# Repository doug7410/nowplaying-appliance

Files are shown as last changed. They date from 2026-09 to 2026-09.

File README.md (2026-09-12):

# Now-Playing appliance

A desk device that listens to the room, figures out what song is playing, and shows it:
a HUB75 LED matrix renders a synced spectrum / lyrics visualization, and a 5" touch
screen shows the cover, title, artist, progress and a mosaic of what played recently.
The whole thing lives in a routed guitar body with three gold knobs and a bat-handle
power toggle.

```
                       room audio
                           │
             ┌─────────────▼──────────────┐
             │  BOARD 1 — the room ear     │  ESP32-S3 running a WLED-MM fork:
             │  I2S mic · HUB75 64×32      │  spectrum / Keybeat / lyrics looks,
             │  panel · 3 knobs            │  uploads mic windows to the cloud
             └──────┬───────────────▲──────┘
      POST /ingest  │               │  GET /lyrics
                    │               │              UART (knobs, re-check, heartbeat)
             ┌──────▼───────────────┴──────┐        │
             │  CLOUD — recognition brain   │        │
             │  songrec → now-playing state │        │
             │  → metadata, lyrics, covers  │        │
             └──────┬───────────────▲──────┘        │
     GET /nowplaying│               │ GET /album/{id}│
             ┌──────▼───────────────┴──────┐        │
             │  BOARD 2 — the touch display │◄───────┘
             │  Raspberry Pi + 5" HDMI/USB  │  native LVGL app (display/)
             └─────────────────────────────┘
```

Both boards authenticate to the cloud with **one shared device token**. The cloud
derives all state server-side; the boards render dumb.

## What is in this repo

| Path | What |
|---|---|
| [`BOM.md`](BOM.md) | The full parts list, with prices and sourcing notes |
| [`docs/assembly.md`](docs/assembly.md) | Order the PCBs, solder them, wire the harness, drill the front panel, first power-on |
| [`docs/board1-firmware.md`](docs/board1-firmware.md) | Build, flash and provision the ESP32-S3 "ear" |
| [`docs/board2-display.md`](docs/board2-display.md) | Set up the Raspberry Pi and run the display app |
| [`docs/cloud.md`](docs/cloud.md) | Running the recognition service and minting the shared token |
| `hardware/carrier-board/` | KiCad source + JLCPCB zip for the interconnect PCB (ESP32-S3 socket, power, HUB75, knobs, mic, Pi) |
| `hardware/knob-board/` | KiCad source + zip for the 3-encoder front-panel PCB. Also the front-panel drilling template |
| `hardware/mic-board/` | KiCad source + zip for the INMP441 breakout adapter |
| `hardware/panelboard/` + [`docs/panelboard.md`](docs/panelboard.md) | **The minimal build:** a standalone HUB75 driver board for a stock ESP32-WROOM-32 dev board, runs upstream WLED-MM unmodified. Just the LED matrix, none of the rest |
| `display/` | The Board 2 display app (LVGL, C++). Runs on the Pi via DRM/KMS, and on a desktop as an SDL simulator |

## Build order

Only want the LED spectrum on a panel? Build the [panelboard](docs/panelboard.md)
instead: one small PCB, a $5 ESP32 dev board, upstream WLED-MM, done. The rest of this
list is the full appliance.

1. Read [`BOM.md`](BOM.md) and order everything. The three PCBs are bare boards from
   JLCPCB, roughly $20 for five of each, hand-soldered.
2. [`docs/assembly.md`](docs/assembly.md): solder the boards, make the four cables, wire
   power, mount the panel and screen.
3. [`docs/cloud.md`](docs/cloud.md): stand up the cloud service and create **one** device
   token. Both boards use it.
4. [`docs/board1-firmware.md`](docs/board1-firmware.md): flash the ESP32-S3 and run the
   provisioning script. The panel should light up with the "Mountain" spectrum.
5. [`docs/board2-display.md`](docs/board2-display.md): image the Pi, run `provision.sh`
   in `display/`. Play a song in the room.

## Status and what is not here yet

This is a working one-off appliance and the design for a small hand-built batch. Every
board in `hardware/` has been fabbed and passes ERC/DRC with zero violations; the pin
maps and current budgets are measured on the bench, not estimated.

Two source trees the build depends on are **not published yet**:

- **The Board 1 firmware** is a fork of [WLED-MM](https://github.com/MoonModules/WLED-MM)
  carrying a `room_mic_uploader` usermod, the Keybeat and lyrics looks, and the HUB75 pin
  map. [`docs/board1-firmware.md`](docs/board1-firmware.md) documents the build exactly
  so it can be reproduced once the fork is pushed.
- **The cloud service** (Laravel + `songrec`). Its HTTP contract is documented in
  [`docs/cloud.md`](docs/cloud.md); the display app in `display/` codes against it.

## License

See [`LICENSE`](LICENSE).

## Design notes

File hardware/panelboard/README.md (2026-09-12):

# panelboard

A minimal board whose only job is driving a HUB75 LED matrix.

No mic, no knobs, no display — 5 V in, a HUB75 connector out, and a plug-in
ESP32 dev board on top. It exists because the Now-Playing appliance's Board 1
does HUB75 rendering buried under a lot of other hardware, and it would be nice
to have the panel half on its own board.

- **MCU:** a stock **ESP32-WROOM-32 38-pin dev board** (the narrow Type-C kind,
  DORHEA/HiLetgo/DevKitC-32 — classic ESP32, *not* an S3), dropped into two 1×19
  female headers. USB, RESET/BOOT and the 3.3 V regulator all come with the
  module, so this board carries none of them.
- **Row spacing is 22.86 mm (0.9").** That is the narrow version, and it is
  measured off the board in hand — a 1.0" wide-version clone is one 0.1" grid
  step wider and **will not seat**. Check yours before ordering.
- **Panel drive:** straight 3.3 V logic, no level shifters. That's what Board 1
  does today and it is hardware-verified on a 64×32 panel.
- **Power:** 5 V in on a screw terminal → AOD403 P-FET reverse-polarity
  protection → a second screw terminal that feeds the panel. Panels pull 2–4 A,
  so the 5 V path is 2.5 mm wide throughout.
- 70 × 72 mm, 2 layers, ground pour on both.

## The pin map is the firmware's, not this repo's

The HUB75 GPIO assignment is **WLED-MM's classic-ESP32 default** — the `#else`
branch at the bottom of `wled00/bus_manager.cpp`, which is the ESP32-Trinity /
mrcodetastic map. Wiring to it means the firmware needs no pinout patch at all.
Don't "improve" it here; change it there and follow.

| HUB75 | GPIO | col | | HUB75 | GPIO | col |
|---|---|---|---|---|---|---|
| R1 | 25 | J1 | | A | 23 | J3 |
| G1 | 26 | J1 | | B | 19 | J3 |
| B1 | 27 | J1 | | C | 5 | J3 |
| R2 | 14 | J1 | | D | 17 | J3 |
| G2 | **12** | J1 | | E | 18 | J3 |
| B2 | 13 | J1 | | LAT | 4 | J3 |
| | | | | OE | 15 | J3 |
| | | | | CLK | 16 | J3 |

**All six RGB pins live in the module's J1 column and all eight control pins in
J3.** That is the single fact the whole layout is built on — see below.

**G2 is on IO12, which is the MTDI strapping pin.** It has to read low at reset
or the chip comes up expecting 1.8 V flash, and the panel's ribbon is the only
other thing on that net. `RPD` (10 k to GND) holds it down rather than trusting
the internal pull-down. It lives under the module: lying flat it is ~2.5 mm tall
against ~8.5 mm of socket clearance.

**E is wired**, to IO18. The 64×32 panel doesn't use it (HUB75 pin 8 is ground
there), but the firmware default already says `e = 18`, so a 64×64 panel is a
config change rather than a respin.

GPIO 6–11 are the SPI flash on a classic ESP32 and are left unconnected, as are
IO0/IO2 (strapping), TX0/RX0, and the input-only pins 34–39.

## Firmware: this is not a drop-in for Board 1's build

A plain ESP-WROOM-32 module is **4 MB flash and no PSRAM**. Board 1's WLED-MM
build (`~/Code/WLED-MM` `platformio_override.ini`, `[env:board1]`) pins
`extreme_partitions` — a 3.2 MB app plus a 9 MB filesystem on 16 MB flash — and
that partition table cannot fit here. Build a stock classic-ESP32 WLED-MM target
for this board. A 64×32 DMA framebuffer fits in internal RAM comfortably; 64×64
at high bit depth will not.

## JP1 — pull the shunt before plugging in USB

A dev board's 5 V pin has no reverse-current protection. Leave it tied to a live
panel supply with a USB cable also plugged in and the supply back-feeds the host
port. `JP1` sits in series with the module's 5 V pin so you can break that path;
it is west of the module body so the shunt has headroom.

## Building it

Everything in `board/` is generated. The `.kicad_sch` and `.kicad_pcb` are
committed artifacts, but the generators are the source of truth — edit those.

```
cd board
make all       # regenerate the schematic and the board from generator/*.py
make check     # ERC + DRC with schematic parity, gating on every severity
make zip       # -> panelboard-jlc.zip, ready to upload to jlcpcb.com
make render    # top.png / bottom.png
```

`gen_sch.py` is deterministic (uuid5-derived), so it re-emits the schematic
byte-for-byte. `gen_pcb.py` is not — pcbnew mints fresh UUIDs on every run, so
`make all` rewrites the whole `.kicad_pcb` even when nothing changed. Regenerate
when the design actually changes, not as a habit.

The board is clean at `--severity-all`: 0 errors, 0 warnings, 0 unconnected,
0 parity issues. There is no expected-warning exception to remember.

## Assembly

**Order it as a bare PCB, not PCBA.** Q1 (AOD403, TO-252) is the only surface
mount part on the board and it hand-solders easily; everything else is through
hole. Paying JLC's assembly setup for one FET is not worth it.

| Ref | Part |
|---|---|
| J_ESP_L, J_ESP_R | 1×19 female header, 2.54 mm |
| J_HUB | 2×08 shrouded IDC header, vertical |
| J_PWR, J_PANEL | Phoenix MSTBVA 2,5/2-G, 5.00 mm |
| JP1 | 1×02 male header + shunt |
| Q1 | AOD403 P-FET, TO-252 |
| RG / RPD | 100 k / 10 k axial |
| CB1 / CB2 | 470 µF 16 V radial D8 / 100 nF disc |

Solder `RPD` before the sockets go in — once the module is plugged in you can't
reach it.

## Layout notes worth knowing before you move anything

- **The HUB75 IDC's pin-1 y is 32.43, not a round number.** That puts every IDC
  row exactly on a *gap* between two J1 socket pads, so each even-column control
  signal crosses the pad wall dead straight — no jog, no via, no chance of
  crossing a neighbour. Move the connector off that grid and eight nets get
  much harder.
- **The control bundle puts every horizontal on B.Cu and every vertical on
  F.Cu.** Two horizontals at different y can't collide and neither can two
  verticals at different x, so the eight nets are collision-proof by
  construction — which matters, because the source order and the destination
  order genuinely disagree (E and B invert, and the four odd-column pins have to
  wrap around the west side of the connector). Costs two vias per net in a
  corridor with room to spare.
- **The corridor between the two socket rows is empty on both layers.** That
  free 22.86 mm channel is the one real thing a socketed module buys you over a
  soldered-down WROOM, and the control fan spends all of it.
- **The board's north edge is at y = 18** so the module's antenna end overhangs
  into free air. The antenna straddles pin 1 — about 3 mm either side — so there
  is no way to socket pin 1 *and* keep the board out from under it. Ending the
  board short is cheaper and better than a copper keepout.
- **Zone clearance is 0.25 mm, not 0.30.** At 0.30 the pour cannot squeeze
  between two 2.54 mm-pitch through-hole pads (2.54 − 2×1.15 = 0.24, under the
  0.25 minimum thickness), the socket rows fence it off, and GND pads end up
  stranded on islands. At 0.25 the gap is 0.34 and it flows. JLC's floor for
  2 layers is 0.2, so this still has margin.
- **Both electrolytics stay south of y = 73.8.** The module's USB port overhangs
  its south end at about 10 mm height and a D8 radial cap is ~11 mm tall — put
  one further north and the cable has nowhere to go.
- The IDC's **shroud courtyard is much larger than its pads** (10 × 29 mm). It
  is the real constraint on the west half of the board, not the pin field.

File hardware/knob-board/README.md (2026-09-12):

# Knob board (KiCad)

The Board-1 front-panel knob PCB: three EC11 rotary encoders (MODE / BRIGHT / GAIN)
plus a switch resistor ladder, out to a single 8-pin JST-XH connector.

This is a **re-creation in KiCad** of the design that was routed in Flux
(`https://www.flux.ai/doug7410/nowplaying-knob-board~ss`). Flux cannot export
`.kicad_pcb`/`.kicad_sch` — only Gerbers, IPC-2581, ODB++, GenCAD and EDIF, none of
which KiCad imports — so the schematic and layout were rebuilt from the Flux Gerber
and IPC-D-356 netlist exports. The KiCad files here are now the source of truth.

## The circuit

Ten nets, six parts. Every footprint is stock KiCad — no custom library.

| Ref | Part | Footprint |
|---|---|---|
| ENC1/2/3 | Alps `EC11E15244G1` | `Rotary_Encoder:RotaryEncoder_Alps_EC11E-Switch_Vertical_H20mm` |
| J1 | JST `B8B-XH-A(LF)(SN)` | `Connector_JST:JST_XH_B8B-XH-A_1x08_P2.50mm_Vertical` |
| R1 | 3.3 kΩ axial | `Resistor_THT:R_Axial_DIN0207_L6.3mm_D2.5mm_P7.62mm_Horizontal` |
| R2 | 10 kΩ axial | same |

**J1 pinout — the harness contract:**

```
1 MODE_A · 2 MODE_B · 3 BRIGHT_A · 4 BRIGHT_B · 5 GAIN_A · 6 GAIN_B · 7 SW_LADDER · 8 GND
```

**The switch ladder.** Three push-switches share one ADC pin. Each switch's common
ties to `SW_LADDER`; the other side goes to GND through a distinct resistance —
ENC1 direct (0 Ω), ENC2 via R1 3.3 kΩ, ENC3 via R2 10 kΩ. The 10 kΩ pull-up to 3V3
and the 100 nF debounce cap live **on the carrier board**, not here; that is why
there is no 3V3 net and the cable is 8 conductors. Levels at GPIO 2 (`ADC1_CH1`):
idle 3.30 V, GAIN 1.65 V, BRIGHT 0.82 V, MODE 0.00 V.

On the KiCad symbol, `A`/`B`/`C` are the rotary section (C is the rotary common →
GND) and `S1`/`S2` are the push-switch. Flux's part model called the same pins
`TERMINAL_A/B/C` and `COM`/`NO`; easy to conflate.

## Geometry

Board **100.0 × 30.0 mm**, rect `(10,10)`–`(110,40)` in KiCad coordinates, centre
`(60,25)`. That frame is deliberately the same one the Flux Gerbers use (Gerber Y is
the negation), so the two can be compared hole-for-hole.

Knob shafts sit at **X = centre −38 / 0 / +38** (38 mm pitch) and **Y = 5 mm above
centre**. The PCB is the front-panel drilling template, so these are the numbers that
have to match the enclosure.

Encoders are on the top layer at 180°; J1, R1 and R2 are on the bottom. The bottom is
a GND pour; the top carries the six quadrature signals.

**Routing.** Pads occupy Y 14.4–25.6 (encoders) and Y 34.59 (J1), leaving a clear
corridor at Y 28–33 across the whole board. Each quadrature signal takes a horizontal
lane there and drops onto its J1 pin; lanes are ordered so no drop ever crosses a lane
still carrying copper at that X. `SW_LADDER` busses all three switch commons and would
have to cross every one of those lanes, so it runs on the **bottom** layer instead —
it just carves a channel through the GND pour, which reconnects around both ends.

## Differences from the Flux board (v2, `a6fcbc93`)

Verified by diffing the drill files:

- **J1, R1, R2 holes are identical** — all 12, exactly.
- **All 15 encoder pins are identical after a deliberate 0.85 mm X shift.** Flux's
  re-route nudged the knob group 0.85 mm right of centre, which broke the left/right
  symmetry (12.85 mm from one edge, 11.15 mm from the other). Here the knobs are
  symmetric: 12.0 mm from each edge.
- **Mounting lugs**: same X, 0.1 mm different in Y, drilled round 2.6 mm vs Flux's
  round 3.0 mm.

This board passes DRC with **0 violations, 0 unconnected pads and 0 schematic-parity
issues**, and JLC's DFM check clean — see below.

## JLC DFM

Ran 2026-08-05 on `knob-board-jlc.zip`: **zero Danger findings in every category** —
no trace/pad spacing, annular ring, edge clearance, soldermask or drill problems.
(The Flux board, by contrast, flagged 21 silkscreen line-width errors, 12
silkscreen-to-pad/hole errors and 11 soldermask-openings-exposing-trace at 0.09 mm.)

Two warnings came back on the first run and are both fixed:

- **Silkscreen line width 0.12 mm (×54).** Stock KiCad footprints ship 0.12 mm silk.
  Everything on F/B.Silkscreen is widened to **0.16 mm** at build time (`SILK_W`), text
  included. Note the exact threshold: **JLC's minimum is 0.153 mm (6 mil), not 0.15** —
  a first attempt at 0.15 mm came back with all 54 warnings intact.
- **Short slot detection 1.3 mm (×6).** The encoder mounting lugs were an oval
  2.8 × 1.5 mm slot; JLC wants a slot at least twice as long as it is wide, and this
  one routed only 1.3 mm. Switched to the stock
  `..._CircularMountingHoles` footprint variant — identical pad positions, but a plain
  round 2.6 mm drill. **The board now has no routed slots at all**, which some fabs
  surcharge for.

If you regenerate the Gerbers, note `make zip` runs `make check` first, so a parity or
DRC regression stops the build rather than silently shipping a stale `gerbers/`.

## Rebuilding

```
make check      # ERC + DRC (with schematic parity); fails on any violation
make gerbers    # gerbers/ + Excellon drill
make zip        # knob-board-jlc.zip — upload this straight to jlcpcb.com
```

`make zip` depends on `check`, so a board that fails DRC can never reach the fab.

**Ordering at JLCPCB:** upload `knob-board-jlc.zip`, then **2 layers, 100 × 30 mm,
1.6 mm, HASL** — every other default is fine. It's a plain 2-layer through-hole board
with no controlled impedance, no blind vias and nothing below 0.35 mm.

Requires `kicad-cli` and the `kicad-library` package (stock symbols and footprints).

Generated output (`gerbers/`, `knob-board-jlc.zip`, `*.rpt`, `*.net`) is gitignored —
the `.kicad_sch` and `.kicad_pcb` are the artifacts that matter.

## Not done

- No silkscreen legend (MODE / BRIGHT / GAIN) next to the knobs — assumed to live on
  the front panel. Say so if the bare board should carry it.
- R1/R2 have no MPN. Irrelevant unless ordering assembly; these are hand-soldered.

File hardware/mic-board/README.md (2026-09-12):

# Now-Playing mic board

Adapter that mounts the proven round **INMP441 I2S MEMS breakout** (Ø14 mm, two
1×3 rows at 7.62 mm) and brings it out to a **6-pin JST-XH** matching the carrier
board's `J_MIC` pinout, 1:1 cable:

| J1 pin | Net | | J1 pin | Net |
|---|---|---|---|---|
| 1 | MIC_SCK | | 4 | GND |
| 2 | MIC_WS | | 5 | P3V3 |
| 3 | MIC_SD | | 6 | GND |

- **L/R is tied to GND on this board** (left channel) — matches WLED-MM
  `digitalmic.type=1` and the Board 1 smoketest wiring.
- Mount the module **label/port side up** (chip side toward this board) on the
  supplied pin headers; the adapter's silk row labels then match the module's.
  The Ø3 mm center hole is acoustic relief so either mounting orientation works.
- Two M3 holes, 14 mm apart, at the top corners.

Built headlessly (kicad-cli 10); `make check` runs ERC + DRC (0 violations,
schematic parity clean), `make zip` builds `mic-board-jlc.zip` for JLCPCB
(2 layers, 20 × 38 mm, 1.6 mm, HASL — bare board, hand-solder the two headers
and the XH).

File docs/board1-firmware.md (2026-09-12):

# Board 1 firmware: the ESP32-S3 ear

Board 1 runs a fork of [WLED-MM](https://github.com/MoonModules/WLED-MM) (MoonModules'
audio-reactive WLED, branch `mdev`) with these additions:

| Piece | What it does |
|---|---|
| `usermods/room_mic_uploader/` | Taps the audio-reactive PCM stream, POSTs mic windows to the cloud's `/ingest`, reads the three EC11 knobs (quadrature in a pin-change ISR), talks to the Pi over UART (knob events, re-check, heartbeat), fetches synced lyrics for the on-panel lyrics look |
| `wled00/FX.cpp` fx 230 "Equalizer LF" | The "Mountain" spectrum: 16 bands, each shown as energy above its own rolling mean |
| `wled00/keybeat_loader.cpp` | Loads beat-synced GIF looks from LittleFS |
| `wled00/bus_manager.cpp` `SECTION9_2_PINOUT` | The HUB75 pin map the carrier board is wired to |
| `pio-scripts/patch_audioreactive.py` | Re-applies a vendored, DSP-patched copy of the audio-reactive usermod after every clean |
| `board1-config/provision-board1.sh` | Post-flash provisioning of everything that lives in WLED's runtime config |

> **Not yet public.** The fork and the vendored assets it pulls from the appliance repo
> (`audio_reactive.h`, the Mountain palette/preset, the Keybeat GIF presets) have not been
> pushed to GitHub yet. Everything below is the exact recipe that builds the shipping
> board, written so it works unchanged once they are. The upstream WLED-MM build alone
> will drive the panel but will not ingest, show lyrics, or talk to the Pi.

## Prerequisites

- PlatformIO (`pip install platformio` or the VS Code extension).
- The ESP32-S3-DevKitC-1 N16R8 on USB (`/dev/ttyACM0` on Linux). **Pull JP1 on the
  carrier first** if the devkit is seated and the carrier is powered.
- A running cloud and the shared device token ([`cloud.md`](cloud.md)).

## 1. Configure the build

Two gitignored files carry the secrets. Create both in the fork's checkout.

`platformio_override.ini`:

```ini
[env:board1]
extends = env:esp32S3_8MB_PSRAM_M_opi

; N16R8 devkit:
board_build.flash_size = 16MB
board_upload.flash_size = 16MB
board_build.partitions = ${esp32.extreme_partitions}   ; 16MB: 3.2MB firmware, 9MB FS
; N8R8 devkit instead: use these three lines. 8MB: 2MB firmware (the build is ~1.9MB), 3.9MB FS
;board_build.flash_size = 8MB
;board_upload.flash_size = 8MB
;board_build.partitions = ${esp32.large_partitions}

upload_port = /dev/ttyACM0
monitor_port = /dev/ttyACM0
upload_speed = 921600
monitor_speed = 115200
monitor_filters = esp32_exception_decoder

build_flags = ${env:esp32S3_8MB_PSRAM_M_opi.build_flags}
  -D WLED_RELEASE_NAME=nowplaying_board1
  -D SECTION9_2_PINOUT              ; HUB75 pins in bus_manager.cpp (matches the carrier)
  -D SR_ENABLE_DEFAULT              ; audioreactive on from first boot
  -D USERMOD_ROOM_MIC_UPLOADER      ; cloud ingest + knobs + UART + lyrics
  -D CLIENT_SSID='"your-wifi-ssid"'
  -D CLIENT_PASS='"your-wifi-password"'
  ; I2S MEMS mic on the carrier: SCK=38 WS=39 SD=40, no MCLK
  -D SR_DMTYPE=1 -D I2S_SDPIN=40 -D I2S_CKPIN=38 -D I2S_WSPIN=39 -D MCLK_PIN=-1
  ; keep WLED's default LED/relay buses off the HUB75 / mic / knob pins
  -D LEDPIN=2 -D RLYPIN=-1

lib_deps = ${env:esp32S3_8MB_PSRAM_M_opi.lib_deps}
```

`usermods/room_mic_uploader/room_mic_uploader_secrets.h` (copy from the `.example`):

```c
#define NP_HOST         "cloud-host-or-ip"   // no scheme; the POST goes over a raw socket
#define NP_PORT         8000
#define NP_INGEST_PATH  "/api/ingest"
#define NP_DEVICE_TOKEN "<the shared appliance token>"   // SAME token as Board 2
```

The vendored `audio_reactive.h` must be reachable at
`../nowplaying/firmware/board1/wled-mm/audio_reactive.h` relative to the fork, or point
`NP_VENDORED_AUDIOREACTIVE` at it. The build fails loudly if it is missing rather than
silently shipping the stock look.

## 2. Build and flash

```sh
pio run -e board1 -t erase  --upload-port /dev/ttyACM0   # clears stale runtime config
pio run -e board1 -t upload --upload-port /dev/ttyACM0
pio device monitor                                        # watch it join WiFi, note the IP
```

## 3. Provision the runtime config

Some of what makes the board work lives in WLED's runtime config on flash, not in the
binary: the HUB75 bus and 2D layout, the **RGB colour order** (this panel swaps red and
green under WLED's GRB default), the local-I2S mic mode with `I2S_FastPath=0`, the boot
preset, the Mountain palette, and the Keybeat GIF assets. A flash erase wipes all of it.
One script restores it:

```sh
./board1-config/provision-board1.sh <board-ip>
```

It POSTs the config, uploads the palette, presets and GIFs, reboots, and verifies
`leds.count == 2048`, audio source `I2S digital`, and boot preset 3 (fx 230, palette
255). It prints `PASS` when the panel is rendering the Mountain look in correct colours
and the mic is ingesting. Idempotent; re-run any time. The config then survives reboots
and OTA updates.

## Knobs

Three bare EC11 encoders: MODE on GPIO 47/48, BRIGHT on 1/12, GAIN on 41/42. Detents
per encoder batch vary (1, 2 or 4 quadrature transitions per click); the divisor is a
calibration constant at the top of `room_mic_uploader.h`. All three push switches share
GPIO 2 through the resistor ladder on the knob board (idle 3.3 V, GAIN 1.65 V, BRIGHT
0.82 V, MODE 0 V). Today only the MODE press does something (jump home); enabling the
other two is a firmware-only change.

The MODE knob cycles looks in the order given by `/npcycle.json` on the board's
filesystem (seeded from `board1-config/npcycle-default.json`). Reorder looks without a
reflash.

## Gotchas that cost real time

- **Panel dark, or red shows green**: runtime config was wiped. Run the provisioning
  script.
- **Mic reads silence (RMS 0)** with a good mic: either `I2S_FastPath` is 1 (the script
  sets 0), or the mic was reseated on a running board. **Reboot after reseating**; I2S
  never recovers from a reconnect on a live board.
- **Panel ghosting**: not seen on this panel at 3.3 V. If a different panel ghosts, put
  an off-the-shelf HUB75 buffer board inline on the ribbon; there is no room for one on
  the carrier.
- **The board and the Pi cannot see each other over WiFi** on many consumer APs (client
  isolation). That is why the knob / re-check link is a UART wire and why the Pi only
  ever talks to the cloud.

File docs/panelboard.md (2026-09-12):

# Panelboard: just the LED matrix

The smallest build in this repo. One 70 × 72 mm board, one stock ESP32 dev board plugged
into it, one HUB75 panel: 5 V in, spectrum out. No mic on the board, no knobs, no
display, no cloud. Upstream WLED-MM drives it unmodified because the board is wired to
WLED-MM's default classic-ESP32 HUB75 pin map (the ESP32-Trinity map).

Design notes, the pin table, and the layout rationale are in
[`hardware/panelboard/README.md`](../hardware/panelboard/README.md). This page is the
build recipe.

## Parts

| Part | Qty | Notes |
|---|---|---|
| Panelboard PCB, `hardware/panelboard/panelboard-jlc.zip` | 1 | JLCPCB: 2 layer, 70 × 72 mm, 1.6 mm, HASL, defaults otherwise. ~$4 for five, bare board |
| **ESP32-WROOM-32 38-pin dev board**, narrow type (DevKitC-32 / HiLetgo / DORHEA, USB-C or micro) | 1 | Classic ESP32, **not** S3. Row spacing must be **0.9" / 22.86 mm**; measure before ordering, a 1.0" clone will not seat |
| 64×32 P4 HUB75 panel, 1/16 scan, with its ribbon and power pigtail | 1 | Same panel as the full appliance |
| 5 V supply, ≥ 3 A, and a way to get it to a screw terminal | 1 | Panel worst case is 2 A (solid white, full brightness); real looks draw ~0.3 A |
| J_ESP_L, J_ESP_R: 1×19 female header, 2.54 mm | 2 | |
| J_HUB: 2×8 shrouded IDC box header, vertical | 1 | |
| J_PWR, J_PANEL: screw terminal, 2 position, 5.00 mm (Phoenix MSTBVA-compatible) | 2 | |
| JP1: 1×2 male header + shunt | 1 | |
| Q1: AOD403 P-channel MOSFET, TO-252 | 1 | The only surface-mount part |
| RG: 100 kΩ axial, RPD: 10 kΩ axial | 1 each | |
| CB1: 470 µF 16 V radial D8, CB2: 100 nF disc | 1 each | |

## Solder

Placement drawings and renders are in `hardware/panelboard/assembly/`
(`placement-top.png`, `placement-bottom.png`, `placement.pdf`, `render-*.png`).

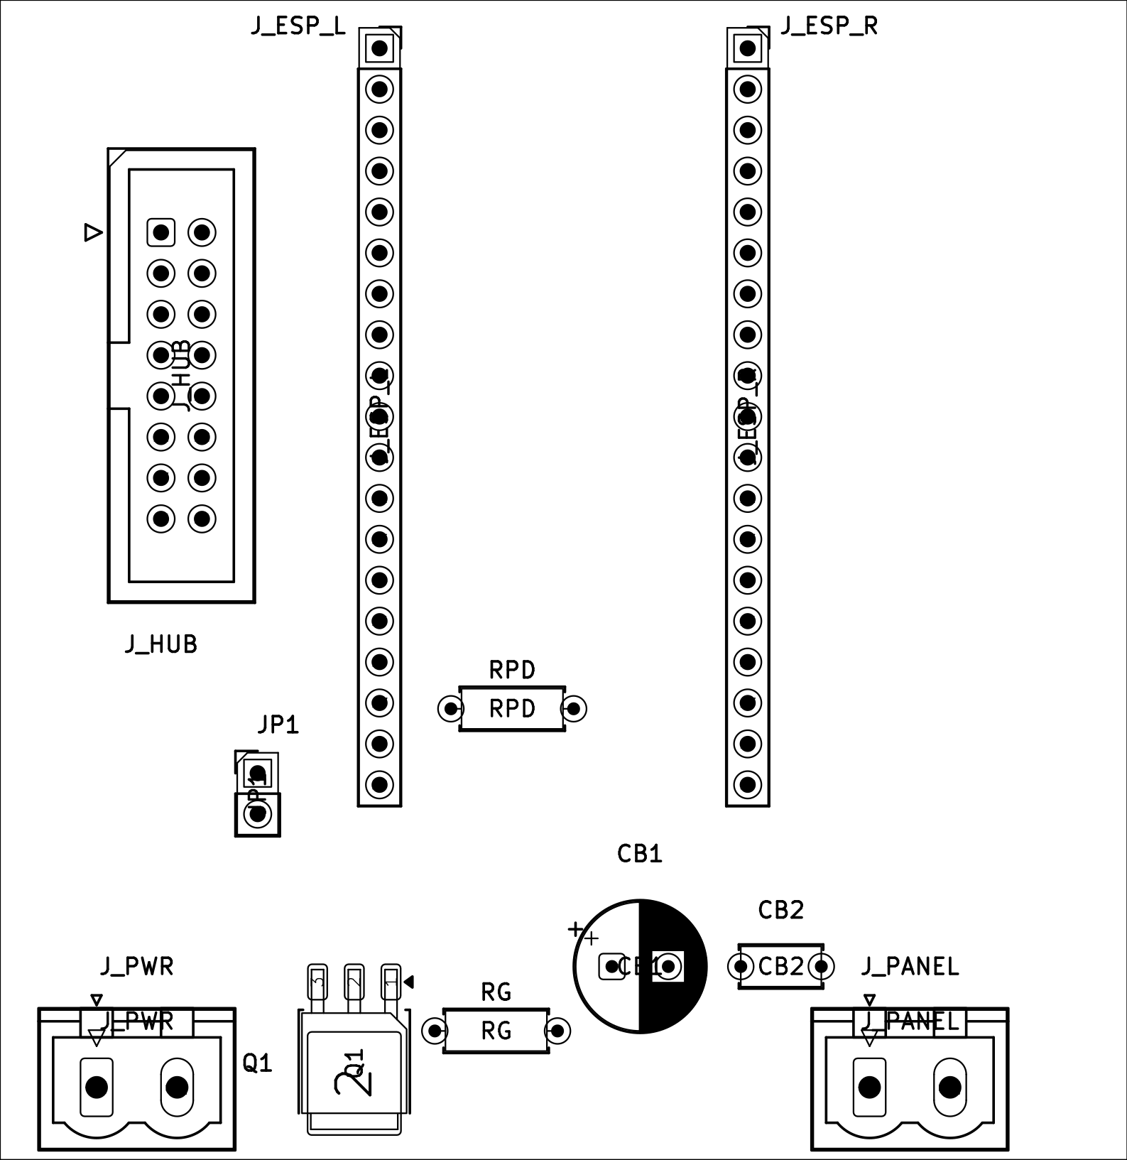
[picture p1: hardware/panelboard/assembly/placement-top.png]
panelboard placement


1. **RPD first.** It sits under the module and is unreachable once the sockets are in.
   It holds IO12 (the G2 line, also the MTDI strapping pin) low at reset; without it
   the chip can come up expecting 1.8 V flash and fail to boot.
2. Q1: tin the tab pad, place, reflow the tab, then the legs. Then RG, CB2, CB1
   (polarity band on the silk).
3. Screw terminals, JP1, the IDC header (key notch as silk-screened).
4. Plug the dev board into both 1×19 sockets, then solder the sockets with the module
   as the alignment jig.

## Wire

```
5 V supply ─► J_PWR ─► Q1 (reverse-polarity) ─► P5V ─┬─► J_PANEL ─► panel power pigtail
                                                     └─► JP1 ─► module 5 V pin
J_HUB ─► panel ribbon ─► panel HUB75 IN
```

The 5 V copper is 2.5 mm wide throughout, sized for the panel's 2–4 A.

**Pull the JP1 shunt before plugging USB into the dev board** while J_PWR is live. The
module's 5 V pin has no reverse-current protection, so a live rail plus a USB cable
back-feeds your computer. Flash over USB with JP1 out, then put the shunt back.

## Firmware

Upstream WLED-MM, branch `mdev`, stock target. Nothing in this repo's Board 1 build
applies: that one needs 16 MB flash and PSRAM, and a plain WROOM-32 has 4 MB and none.

```sh
git clone -b mdev https://github.com/MoonModules/WLED-MM.git && cd WLED-MM
pio run -e esp32_4MB_V4_S_HUB75 -t upload     # JP1 out, USB in
```

That target's HUB75 pinout is the one the board is wired to; do not add a pinout
override. A 64×32 DMA framebuffer fits in internal RAM; 64×64 at high bit depth will
not (the board does wire the E line, so a 64×64 panel is only a config change).

Then join the board to WiFi (WLED-AP captive portal) and, in the web UI:

- **Config → LED Preferences:** LED type **HUB75**, length **2048**, the "pin" field
  is the panel chain length (**1**), colour order **RGB**. The Waveshare P4 panel swaps
  red and green under WLED's default GRB.
- **Config → 2D Configuration:** one panel, **64 × 32**.
- **Config → Sound Settings:** whatever source you have; a UDP sound-sync sender on the
  LAN, or an I2S mic wired to the module's free pins: GPIO 32, 33, 21, 22 are
  unconnected outputs (SCK, WS), and the input-only 34–39 take the data line (SD).
- Pick an audio-reactive 2D effect (GEQ, Waverly, 2D Swirl...) and save it as the boot
  preset.

Those settings live in the board's flash config, not the binary. Export them from
Config → Security & Updates → Backup once you like them.

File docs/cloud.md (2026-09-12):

# The cloud: recognition service

The boards do no recognition themselves. Board 1 uploads short mic windows; a Laravel
service runs them through [`songrec`](https://github.com/marin-m/SongRec) (a headless
Shazam client), derives per-appliance now-playing state, enriches it in a queue worker
(duration and tracklist from iTunes, synced lyrics from NetEase / LRCLIB, covers via
Cloudinary), and serves it back over five HTTP endpoints. One instance serves any number
of appliances; each appliance is a tenant identified by its bearer token.

> **Not yet public.** The service source is not published. This page documents the
> contract the boards are built against and what running an instance involves, so the
> rest of the build is reproducible the day it is.

## Running an instance

- PHP 8.3 + Composer, SQLite (local) or Postgres.
- `songrec` 0.7.3 on the PATH (`songrec audio-file-to-recognized-song <wav>` is the
  only call made).
- A Cloudinary account with **fetched URLs enabled** for cover-art resizing.
- Two foreground processes:

```sh
php artisan serve --host=0.0.0.0 --port=8000        # bind the LAN so the boards reach it
php artisan queue:work --queue=database --tries=1   # fills duration / lyrics / album
```

Config knobs in `.env`: `NP_FRESHNESS_TIMEOUT=90` (seconds without an ingest before the
state decays), `NP_IDLE_AFTER=3` (consecutive misses before `idle`), `NP_RECENT_MAX=90`.
The defaults fit the boards' cadences (Board 1 uploads every ~33 s, Board 2 polls every
3–5 s). Leave them.

## Mint the appliance token

```sh
php artisan device:create      # prints the token once
```

**One appliance = one device = one token.** Put the same token in Board 1's
`room_mic_uploader_secrets.h` and Board 2's `pi/np.env`. Both `/nowplaying` and the
recent mosaic are scoped to the authenticated device, so a second token is a second,
empty appliance that shows "Listening" forever.

## The contract

All endpoints except `/health` take `Authorization: Bearer <token>`. CORS is open
(`Access-Control-Allow-Origin: *`) so a browser on the LAN can also read it.

| Method + path | Caller | Purpose |
|---|---|---|
| `GET /api/health` | anyone | liveness, no auth |
| `POST /api/ingest` | Board 1 | multipart field `file`: a **16 kHz mono 16-bit PCM WAV**, 8–18 s, RMS-gated. Recognised inline. Returns `{matched, track_id, title, artist}` |
| `GET /api/nowplaying` | Board 2 | current state + track + cover + position + recent tiles |
| `GET /api/album/{id}` | Board 2 | tracklist for a recent tile, the heard track flagged |
| `GET /api/lyrics?track_id=…` | Board 1 | synced `yrc` / `lrc`; `pending: true` until the worker has run |

`GET /api/nowplaying`:

```json
{ "state": "playing",
  "track_id": "…", "title": "…", "artist": "…", "album": "…",
  "cover_url": "https://res.cloudinary.com/…",
  "duration_s": 301, "position_s": 42.0,
  "lyrics_available": true,
  "recent": [ { "id": "…", "cover_url": "…" } ] }
```

- `state` is `setup`, `playing` or `idle`, derived server-side. Track fields are null
  unless `playing`.
- `position_s` is computed at request time. Interpolate the progress bar from the
  moment the response arrived and re-snap on every poll; there is no anchor timestamp.
- `recent[]` tiles carry only `id` and `cover_url`; `id` feeds `/album/{id}`.
- The WAV upload is MIME-sniffed. A malformed header is a 422 even if the PCM decodes.
  This is the number-one real-hardware failure mode.

## A note on recognition

`songrec` talks to Shazam's unofficial endpoint. It is free and it works, and it is also
a terms-of-service and reliability risk for anything you sell: if the endpoint changes,
every fielded unit goes quiet until the cloud is patched. The design keeps all vendor
calls server-side for exactly that reason, so swapping to a licensed API (AudD, ACRCloud)
is a cloud-only change that never touches a board.

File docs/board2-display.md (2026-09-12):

# Board 2: the Raspberry Pi display

Board 2 is a Raspberry Pi driving the 5" 800×480 HDMI touch panel with the native
LVGL app in [`display/`](../display/README.md). No desktop, no compositor, no browser:
the app draws straight to the screen through DRM/KMS on tty1 and reads touch from evdev.
It polls the cloud's `GET /nowplaying` every few seconds and `GET /album/{id}` when a
cover is tapped, and renders four screens: Now Playing, Listening (idle), Recently
(cover mosaic), Album.

Verified on a Pi 3B. Any Pi with a 40-pin header and HDMI out works; the app's working
set is 30–60 MB.

## 1. Image the Pi

Raspberry Pi OS **Lite** (Debian 12 or 13), 64-bit. In the imager set a hostname, a
user, WiFi, and enable SSH. Boot it headless and `ssh` in.

## 2. Free the UART for the Board 1 link

The carrier's J_PI cable puts Board 1's serial on header pins 8/10. Take Bluetooth off
the good UART and stop the kernel using it as a console:

```sh
sudo sed -i 's/ console=serial0,115200//' /boot/firmware/cmdline.txt
printf 'enable_uart=1\ndtoverlay=disable-bt\n' | sudo tee -a /boot/firmware/config.txt
sudo systemctl disable serial-getty@ttyS0 serial-getty@ttyAMA0
sudo reboot
```

After the reboot `/dev/serial0` is the PL011 (`ttyAMA0`), 115200 8N1.

## 3. Build and install the display app

On the Pi:

```sh
git clone <this repo> && cd nowplaying-appliance/display
cp pi/np.env.example pi/np.env
$EDITOR pi/np.env          # NP_BASE_URL = http://<cloud-host>:8000/api
                           # NP_TOKEN    = the SHARED appliance token (same as Board 1)
./provision.sh             # apt deps → cmake build → np-display.service on tty1
```

`provision.sh` is idempotent: re-run it after pulling changes. It installs a systemd
unit that owns tty1 (`Conflicts=getty@tty1`, `PAMName=login` so the process gets a
logind seat and can take DRM master) and restarts on failure. Logs:

```sh
journalctl -u np-display -f
```

If DRM will not initialise on your Pi/OS combination, `DISPLAY_BACKEND=fbdev
./provision.sh` writes `/dev/fb0` directly instead. It tears slightly but never fights
for DRM master.

The touch panel enumerates as `/dev/input/event0` (QDtech MPI5001). If it lands
elsewhere, set `NP_TOUCH_DEV` in `pi/np.env`.

## 4. The one trap: the token

`/nowplaying` and the recent mosaic are scoped **per device**. If the Pi uses a token
other than the one Board 1 ingests under, it reads an empty tenant and shows
"Listening" forever, with no error anywhere. One appliance, one token, on both boards.

## 5. Make it survive the power toggle

The master toggle is a hard cut. Either enable the overlay read-only root
(`sudo raspi-config` → Performance → Overlay File System) once everything is set up, or
on a Pi 4 boot from a USB SSD. Remember to disable the overlay before the next
`provision.sh`.

## 6. Seeing it without hardware

`display/sim/run.sh` builds the same `src/ui.cpp` into an 800×480 SDL window on a
desktop, fed by the live cloud (needs SDL2 + libcurl dev packages, and
`src/secrets.h` copied from its `.example` with the token). Mouse = touch, drag to page
the mosaic. This is where the UI is developed; the Pi build only swaps the platform
layer.

## Known gaps

- The knob-toast, re-check and "ear down" overlays are present in the UI but the
  UART bridge that drives them in the LVGL app is not wired up yet (the frame codec
  is `display/src/uart_link.h`; the ESP32 side already sends). They stay dormant until
  that lands.
- The accent colour is fixed rather than sampled from the cover.

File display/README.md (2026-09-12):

# nowplaying-display

Native **LVGL** display app for the Now-Playing appliance's Board 2 (the touch screen).
Replaces the Chromium kiosk (`~/Code/nowplaying-pi`) so it fits a 512 MB Pi
(Zero 2 W / 3A+) — LVGL's working set is ~30–60 MB vs Chromium's ~450 MB.

Renders the same four-screen 800×480 design (Now Playing / Listening / Recently / Album)
the kiosk built, fed by the frozen cloud contract (`GET /nowplaying`, `GET /album/{id}`).

## Layout

- `src/ui.cpp` — the LVGL UI (the screens). The only file with the new design in it.
- `src/ui.h` / `ui_platform.h` — UI public surface + the host shims it needs.
- `src/now_playing.h` — the cloud contract structs (`NowPlaying`, `Album`, …).
- `src/uart_link.h` — codec for the deferred ESP32↔Pi knob/recheck bridge.
- `sim/` — SDL desktop simulator: runs `src/ui.cpp` in an 800×480 window against the
  **live** cloud (libcurl + stb_image in `backend.cpp`). This is how you see it without
  hardware.

## Run the sim

```sh
cp src/secrets.h.example src/secrets.h   # fill in BASE_URL + the SHARED appliance token
cd sim && ./run.sh                        # first run fetches LVGL + stb_image + json
```

Needs SDL2 + libcurl dev packages. Mouse = touch; drag to page the mosaic.

## On the Pi

`pi/` is the platform layer the sim's `sim/` is to SDL: LVGL on the Linux **DRM/KMS**
(default) or **fbdev** display driver + **evdev** touch — no compositor, no browser. It
reuses `src/ui.cpp`, `src/now_playing.h`, and `sim/backend.cpp` unchanged; only the entry
point (`pi/main.cpp`) and `pi/lv_conf.h` differ from the sim.

Deploy mirrors the kiosk (`provision.sh` + a systemd unit), run **on the Pi**:

```sh
cp pi/np.env.example pi/np.env     # set NP_TOKEN (the SHARED appliance token) + NP_BASE_URL
./provision.sh                     # apt deps -> build -> install + start np-display.service
#   DISPLAY_BACKEND=fbdev ./provision.sh   # if DRM won't win master on the VT
```

Notes:
- Token/host come from `pi/np.env` via the unit's `EnvironmentFile` (out of git + the binary);
  `backend.cpp` reads `NP_TOKEN`/`NP_BASE_URL` env, falling back to `src/secrets.h`.
- DRM master is exclusive — the unit takes tty1 (`Conflicts=getty@tty1`, `PAMName=login`)
  and `provision.sh` disables the old `np-kiosk`. fbdev sidesteps the master fight.
- Touch panel = `/dev/input/event0` (QDtech MPI5001); override with `NP_TOUCH_DEV` if it moves.
- Build only the app target: `cmake --build pi/build --target np-display` (skips lvgl demos).

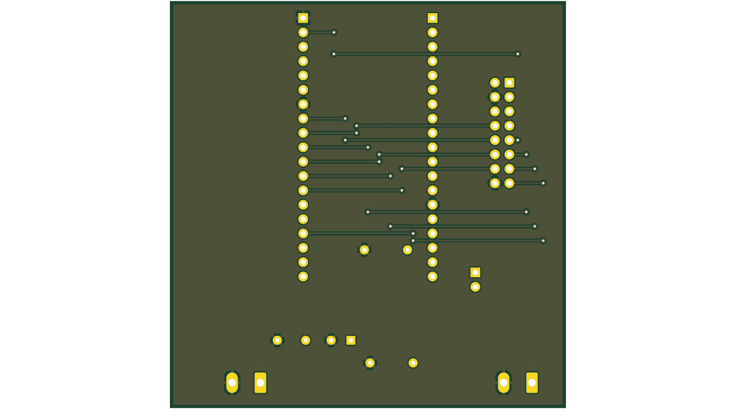
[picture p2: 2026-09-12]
hardware/panelboard/bottom.png

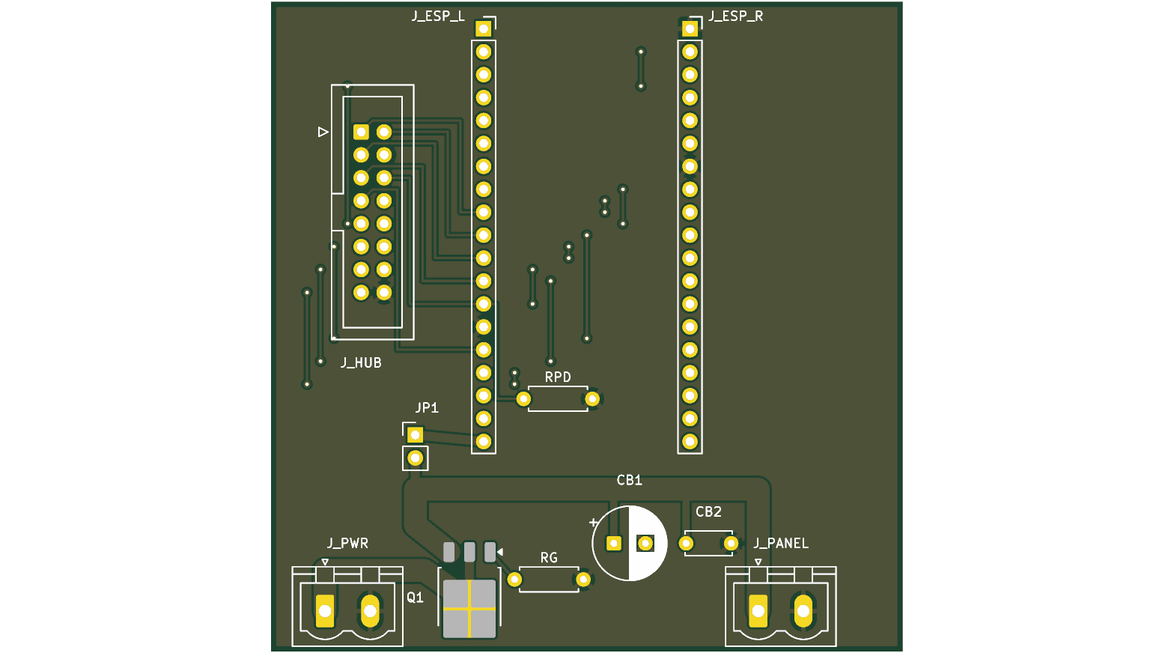
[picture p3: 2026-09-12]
hardware/panelboard/top.png

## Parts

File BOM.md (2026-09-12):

# Bill of materials

One appliance = Board 1 (ESP32-S3 "ear") + Board 2 (Raspberry Pi display) + the
interconnect PCBs + one enclosure. Prices are USD, small-quantity retail, rounded. Where
a part is a specific SKU that matters, it says so and why.

The custom PCBs are ordered as **bare boards** and hand-soldered. Every part on them is
through-hole except one DPAK MOSFET, which hand-solders fine.

## Board 1 — the ear

| # | Part | Qty | ~$ | Notes |
|---|---|---|---|---|
| 1 | **ESP32-S3-DevKitC-1**, genuine Espressif: **N16R8** (16 MB flash, 8 MB octal PSRAM) or **N8R8** (8 MB flash) | 1 | 15 | Plugs into the carrier's two 1×22 sockets. **Must be the genuine Espressif board with 22.86 mm (0.9") row spacing**: [Espressif's dimension drawing](https://dl.espressif.com/dl/schematics/esp_idf/DXF_ESP32-S3-DevKitC-1_V1.1_20220429.pdf) shows a 25.40 mm board with each pin row inset 1.27 mm, and the [user guide](https://docs.espressif.com/projects/esp-dev-kits/en/latest/esp32s3/esp32-s3-devkitc-1/user_guide_v1.1.html) says all -1 / -1U variants share that PCB. Every Amazon "N16R8 DevKitC-1" listing is a clone with 1.0" rows and will not seat. Buy from Mouser: N8R8 is stocked (`356-EP32S3DVKTC1N8R8`); N16R8 (`356-ESP32S3DKC1N16R8`) is factory-order. N8R8 needs the 8 MB partition table, see the firmware page; the firmware and assets fit either. |
| 2 | **64×32 P4 HUB75 LED matrix**, 1/16 scan, e.g. Waveshare RGB-Matrix-P4-64x32 | 1 | 30 | Buy a branded, restockable SKU new. Comes with the 16-pin ribbon and the power pigtail. Driven at 3.3 V logic with no level shifter, bench-verified. |
| 3 | **INMP441 I2S MEMS mic breakout**, the round Ø14 mm module with two 1×3 rows 7.62 mm apart | 1 | 3 | The mic board is cut for this exact module. INMP441 is EOL at TDK but modules are plentiful. Do not substitute SPH0645: WLED-MM's SPH0645 timing fix is classic-ESP32 only and is a no-op on the S3. |
| 4 | Carrier board PCB, `hardware/carrier-board/carrier-board-jlc.zip` | 1 | 11 / 5 pcs | JLCPCB: 2 layer, 140 × 100 mm, 1.6 mm, 1 oz, HASL. Everything else default. |
| 5 | Knob board PCB, `hardware/knob-board/knob-board-jlc.zip` | 1 | 2 / 5 pcs | JLCPCB: 2 layer, 100 × 30 mm, 1.6 mm, HASL. |
| 6 | Mic board PCB, `hardware/mic-board/mic-board-jlc.zip` | 1 | 4 / 5 pcs | JLCPCB: 2 layer, 20 × 38 mm, 1.6 mm, HASL. |
| 7 | Carrier board parts (table below) | 1 set | 8 | |
| 8 | Knob board parts (table below) | 1 set | 6 | |
| 9 | Mic board parts (table below) | 1 set | 1 | |
| 10 | Knob caps, 6 mm D-shaft, set-screw, gold knurled dome | 3 | 6 | Guitar-knob aesthetic. |
| 11 | **Master power toggle**: SPST bat-handle, rated ≥10 A DC, gold, with a Gibson-style "poker chip" ring | 1 | 6 | Switches the 5 V rail, never mains. RHYTHM up = ON. |
| 12 | **Panel-mount DC jack**, DC-099 style, 5.5 × 2.1 mm, threaded | 1 | 2 | Bolts through the enclosure wall so plug force lands on the wood, not a PCB. |
| 13 | **5 V power brick**, 5.5 × 2.1 mm plug, **≥ 6 A** (10 A gives headroom) | 1 | 25 | Measured budget: panel 2.0 A worst case (solid white, full brightness; 0.3 A in real use), Pi up to 3 A, ESP32 0.5 A. The brick stays outside the enclosure. |

### Carrier board parts

Matches `hardware/carrier-board/assembly/bom-jlc.csv` (LCSC part numbers are in that
file). All through-hole except Q1.

| Ref | Part | Qty | Footprint |
|---|---|---|---|
| Q1 | AOD403 P-channel MOSFET (reverse-polarity protection) | 1 | TO-252 / DPAK |
| R1–R7 | 10 kΩ ¼ W axial | 7 | axial, 7.62 mm pitch |
| RG | 100 kΩ ¼ W axial | 1 | axial |
| C1–C6 | 10 nF 50 V X7R leaded ceramic | 6 | disc, 5 mm pitch |
| C3V3, C7, CB2 | 100 nF X7R leaded ceramic | 3 | disc, 5 mm pitch |
| CB1 | 470 µF 10 V electrolytic | 1 | radial D8, 3.5 mm pitch |
| J_PWR, J_SW, J_PANEL | Screw terminal, 2 position, 5.00 mm pitch | 3 | Phoenix MSTBVA-compatible (KF2EDGVC-5.0-2P clones are fine) |
| J_KNOBS | JST B8B-XH-A | 1 | XH 2.5 mm, 8 pin |
| J_MIC | JST B6B-XH-A | 1 | XH, 6 pin |
| J_PI | JST B5B-XH-A | 1 | XH, 5 pin |
| JP1, JP2, JP3 | 1×2 pin header 2.54 mm **+ 3 shunts** | 3 | |
| J_ESP_L, J_ESP_R | 1×22 female pin socket 2.54 mm | 2 | The ESP32-S3 devkit plugs in here |
| J_HUB | 2×8 IDC box header 2.54 mm, shrouded, with key notch | 1 | The panel ribbon plugs in here |

### Knob board parts

| Ref | Part | Qty |
|---|---|---|
| ENC1–3 | Alps **EC11E15244G1** rotary encoder with push switch, 20 mm shaft, threaded bushing | 3 |
| J1 | JST B8B-XH-A | 1 |
| R1 | 3.3 kΩ ¼ W axial | 1 |
| R2 | 10 kΩ ¼ W axial | 1 |

### Mic board parts

| Ref | Part | Qty |
|---|---|---|
| J1 | JST B6B-XH-A | 1 |
| — | 1×3 pin header, 2.54 mm (mounts the INMP441 module) | 2 |

### Cables

| Cable | From → to | Notes |
|---|---|---|
| Knobs | carrier J_KNOBS → knob board J1 | 8-conductor JST-XH, **straight through 1:1** |
| Mic | carrier J_MIC → mic board J1 | 6-conductor JST-XH, straight through |
| Pi | carrier J_PI → Pi 40-pin header pins 2, 4, 6, 8, 10 | 5-conductor: XH housing on one end, 2.54 mm female Dupont on the other. Straight through; the UART crossover is on the carrier. |
| Panel data | carrier J_HUB → panel HUB75 IN | The 16-pin ribbon that ships with the panel |
| Panel power | carrier J_PANEL → panel power connector | The pigtail that ships with the panel, into the screw terminal. Do not run panel current through anything thinner. |
| DC in | jack lugs → carrier J_PWR; toggle → carrier J_SW | 18 AWG or heavier, carries the full ~6 A |

JST-XH housings + crimp contacts (or pre-crimped XH leads) for 8, 6 and 5 positions.

## Board 2 — the display

| # | Part | Qty | ~$ | Notes |
|---|---|---|---|---|
| 1 | **Raspberry Pi** with a 40-pin header and HDMI out | 1 | 35–55 | The display app is native LVGL (~30–60 MB), so RAM is not a constraint. **Verified on a Pi 3B**; a Pi 4 (2 GB) is the pick for a new build (in production, supports USB boot). A Zero 2 W is the app's design target but not yet hardware-verified, and needs a mini-HDMI adapter and a micro-USB OTG cable for the touch panel. |
| 2 | microSD, 16 GB+, endurance grade (or a USB SSD on a Pi 4) | 1 | 8 | The master toggle is a hard power cut. Use read-only root (overlayfs) or USB boot so cuts are safe. |
| 3 | **5" 800×480 IPS HDMI display with USB capacitive touch**, USB-powered (Hosyond; the touch controller enumerates as QDtech MPI5001) | 1 | 40 | HDMI video + USB touch = zero GPIO use. **Avoid** the DSI variant and resistive eBay units. Verify the listing says capacitive. |
| 4 | Short HDMI cable (Pi 3B/4: full/micro HDMI to HDMI as appropriate) | 1 | 4 | |
| 5 | Short USB-A to micro-USB cable | 1 | 2 | Screen power + touch, from a Pi USB port |

The Pi has **no separate power supply**: it is fed 5 V on header pins 2 and 4 from the
carrier board through the master toggle. Powering over the header bypasses the Pi's
input fuse and polyfuse, which is fine here because the carrier's MOSFET and the brick's
own protection are upstream.

## Enclosure

| Part | Notes |
|---|---|
| Double-cut guitar body blank (or a used body) | Displays inset into the top, control cavity routed from the rear, jack-plate power inlet on the rim |
| Front acrylic: **TAP Plastics Chemcast "Black LED" 1/8"** | Black when off, transmits when lit. **Not** "Black Opaque" (0 % transmission). Gray smoke acrylic is the cheap substitute. |
| Diffuser: **TAP frosted P95 "Lighting White" 69 % transmission, 1/8"** | **Not** Matte White 9 % (too dim), **not** clear (hot spots). |
| M2.5 nylon standoff kit | Stack to a ~5 mm air gap between panel and diffuser. Tune softness with the gap. |
| Passive heatsink for the Pi | **No fan**: the mic would hear it. Vent the cavity. |
| Fasteners, hookup wire, heat-shrink | |

## Panelboard: the matrix-only build

Not part of the appliance; an alternative to it. One PCB, one stock ESP32-WROOM-32 dev
board, one panel, one 5 V supply. Full parts table and recipe in
[`docs/panelboard.md`](docs/panelboard.md).

| Bucket | ~$ |
|---|---|
| Panelboard PCB (5 pcs) + parts | 12 |
| ESP32-WROOM-32 38-pin dev board (narrow, 0.9" rows) | 5 |
| 64×32 P4 HUB75 panel | 30 |
| 5 V ≥3 A supply | 10 |
| **Total** | **~$57** |

## Roll-up

| Bucket | ~$ |
|---|---|
| Board 1 electronics (incl. PCBs and parts) | 115 |
| Board 2 electronics | 95 |
| Cables, switch, jack, brick | 35 |
| Enclosure materials | 40–130 |
| **Total materials** | **~$285–375** |

Cloud hosting is an operating cost shared across all appliances, not a per-unit part.

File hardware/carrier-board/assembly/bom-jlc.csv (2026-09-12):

Comment | Designator | Footprint | LCSC Part #
AOD403 P-FET | Q1 | TO-252-3_TabPin2 | C28969
10k axial 1/4W | R1,R2,R3,R4,R5,R6,R7 | R_Axial_DIN0207_P7.62mm | C61299
100k axial 1/4W | RG | R_Axial_DIN0207_P7.62mm | C120103
10nF 50V X7R leaded MLCC | C1,C2,C3,C4,C5,C6 | C_Disc_D5.0mm_P5.00mm | C1620232
100nF 100V X7R leaded MLCC | C3V3,C7,CB2 | C_Disc_D5.0mm_P5.00mm | C1622885
470uF 10V radial D8 P3.5 | CB1 | CP_Radial_D8.0mm_P3.50mm | C1579341
Screw terminal header 5.00mm 2P (MSTBVA-compatible) | J_PWR,J_SW,J_PANEL | PhoenixContact_MSTBVA_2,5_2-G | C441375
JST B8B-XH-A | J_KNOBS | JST_XH_B8B-XH-A_Vertical | C157972
JST B6B-XH-A | J_MIC | JST_XH_B6B-XH-A_Vertical | C144397
JST B5B-XH-A | J_PI | JST_XH_B5B-XH-A_Vertical | C157991
Pin header 1x2 2.54mm | JP1,JP2,JP3 | PinHeader_1x02_P2.54mm | C32713268
Pin socket 1x22 2.54mm | J_ESP_L,J_ESP_R | PinSocket_1x22_P2.54mm | C41376161
IDC box header 2x8 2.54mm | J_HUB | IDC-Header_2x08_Latch | C53207556

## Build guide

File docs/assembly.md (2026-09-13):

# Assembly

Order: fab the PCBs → solder them → make the cables → wire power → bench test with
nothing seated → seat the boards → mount in the enclosure.

## 1. Order the PCBs

Upload each zip to jlcpcb.com. Every board is a plain 2-layer through-hole board: no
controlled impedance, no blind vias, nothing under 0.35 mm. Defaults are fine except
the size, which JLC reads from the Gerbers anyway.

| Board | File | Size | Copper |
|---|---|---|---|
| Carrier | `hardware/carrier-board/carrier-board-jlc.zip` | 140 × 100 mm | **1 oz** (the 5 V traces are 4 mm wide, sized for 1 oz at 6 A) |
| Knob | `hardware/knob-board/knob-board-jlc.zip` | 100 × 30 mm | 1 oz |
| Mic | `hardware/mic-board/mic-board-jlc.zip` | 20 × 38 mm | 1 oz |

Order bare boards, no assembly. All three passed JLC's DFM check with zero Danger
findings. To regenerate a zip from source you need `kicad-cli` (KiCad 9/10) plus the
stock symbol and footprint libraries; `make zip` in each board directory runs ERC + DRC
first and refuses to build from a board with violations.

## Where the parts go

Every board directory has an `assembly/` folder with placement drawings and renders,
regenerated from the KiCad files by `hardware/render-assembly.sh`:

| File | What |
|---|---|
| `placement-top.png`, `placement-bottom.png` | Outline + footprint outlines + reference designators, as you look at that side (bottom is mirrored) |
| `placement.pdf` | The same, one page per layer, printable |
| `render-top.png`, `render-bottom.png` | 3D render of the bare board with silkscreen |

Carrier board, top:

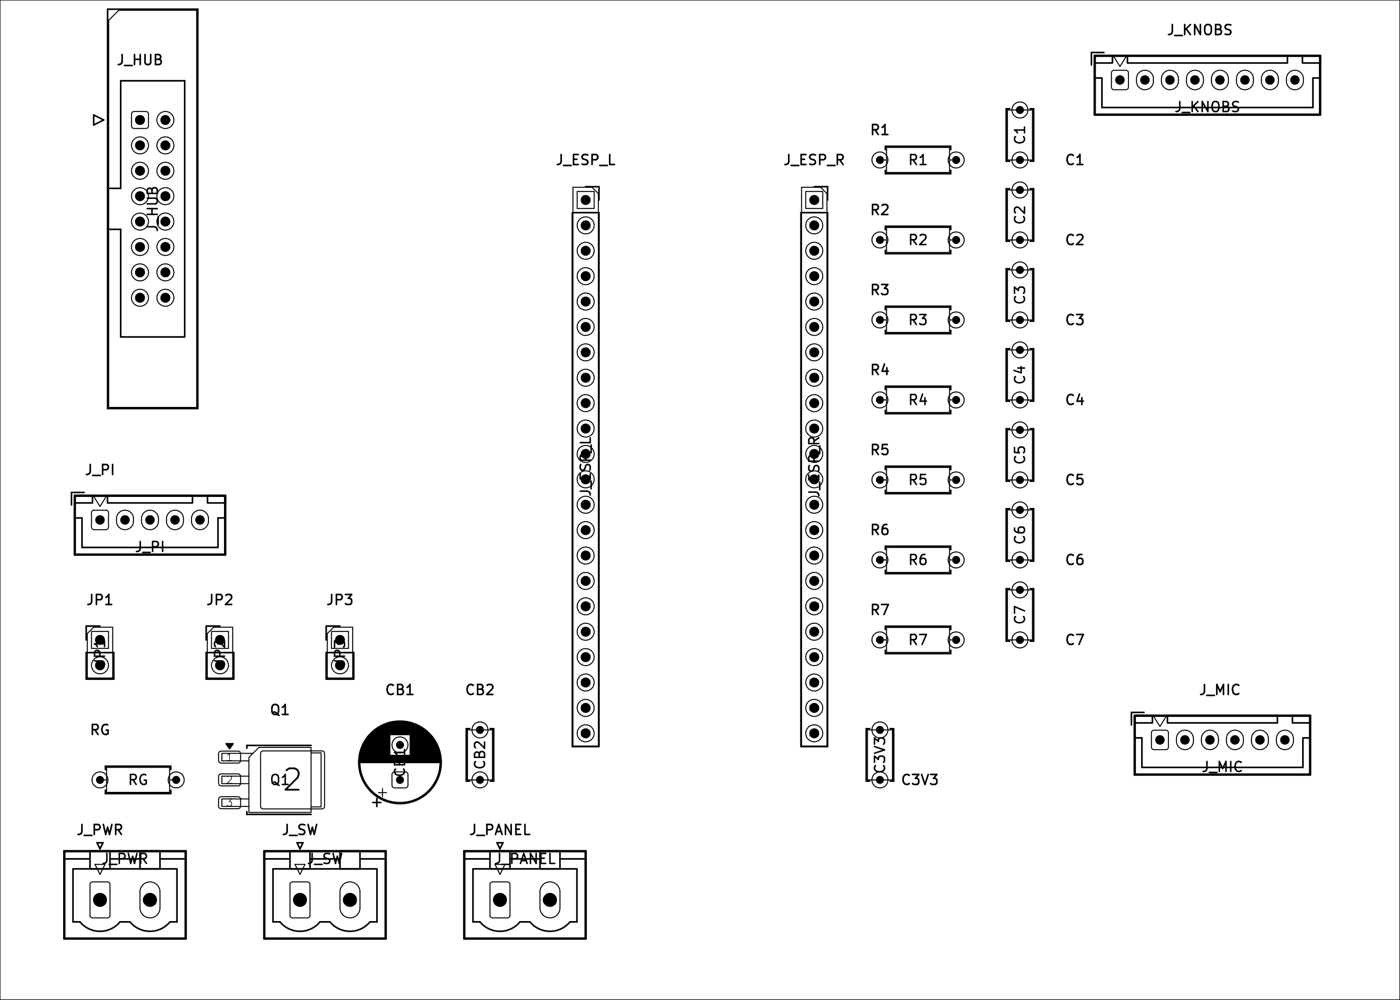
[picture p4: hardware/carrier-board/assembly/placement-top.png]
carrier board placement


## 2. Solder the carrier board

Parts (LCSC numbers in `hardware/carrier-board/assembly/bom-jlc.csv`):

| Ref | Part | Qty |
|---|---|---|
| Q1 | AOD403 P-channel MOSFET, TO-252 / DPAK | 1 |
| R1–R7 | 10 kΩ ¼ W axial | 7 |
| RG | 100 kΩ ¼ W axial | 1 |
| C1–C6 | 10 nF 50 V X7R leaded ceramic, 5 mm pitch | 6 |
| C3V3, C7, CB2 | 100 nF X7R leaded ceramic, 5 mm pitch | 3 |
| CB1 | 470 µF 10 V electrolytic, radial D8, 3.5 mm pitch | 1 |
| J_PWR, J_SW, J_PANEL | Screw terminal, 2 position, 5.00 mm pitch | 3 |
| J_KNOBS | JST B8B-XH-A | 1 |
| J_MIC | JST B6B-XH-A | 1 |
| J_PI | JST B5B-XH-A | 1 |
| JP1, JP2, JP3 | 1×2 pin header 2.54 mm + shunt | 3 |
| J_ESP_L, J_ESP_R | 1×22 female pin socket 2.54 mm | 2 |
| J_HUB | 2×8 IDC box header 2.54 mm, shrouded, keyed | 1 |

Order of operations: shortest parts first. Resistors and ceramics, then Q1, then CB1,
then the headers and sockets, then the screw terminals and JST connectors, then the IDC
header.

- **Q1 (AOD403, DPAK)** is the only surface-mount part. Tin the tab pad, place, reflow
  the tab with a broad tip, then the two legs. Orientation: the silk shows the outline
  and pin 1.
- **CB1 (470 µF)** is polarized. The silk has a hatched band on the negative side.
- **J_ESP_L / J_ESP_R sockets**: plug the ESP32-S3 devkit into both sockets *before*
  soldering them so they end up parallel, then solder with the devkit as the jig. Row
  spacing is 22.86 mm; if your devkit does not drop in freely it is the wrong (1.0")
  board, see the BOM.
- **J_HUB (IDC 2×8)**: key notch faces the board edge, matching the ribbon's key. Pin 1
  is marked on the silk.
- **JST connectors**: shroud opening (pin 1 mark) as silk-screened.
- Fit **shunts on JP1, JP2, JP3** for normal operation. See §5 for when to pull them.

Nets and connector pinouts are in `hardware/carrier-board/generator/gen_carrier_sch.py`
(the schematic is generated from that file, so the file is the readable version).

## 3. Solder the knob board

| Ref | Part | Qty |
|---|---|---|
| ENC1–3 | Alps EC11E15244G1 rotary encoder with push switch, 20 mm shaft, threaded bushing | 3 |
| J1 | JST B8B-XH-A | 1 |
| R1 | 3.3 kΩ ¼ W axial | 1 |
| R2 | 10 kΩ ¼ W axial | 1 |

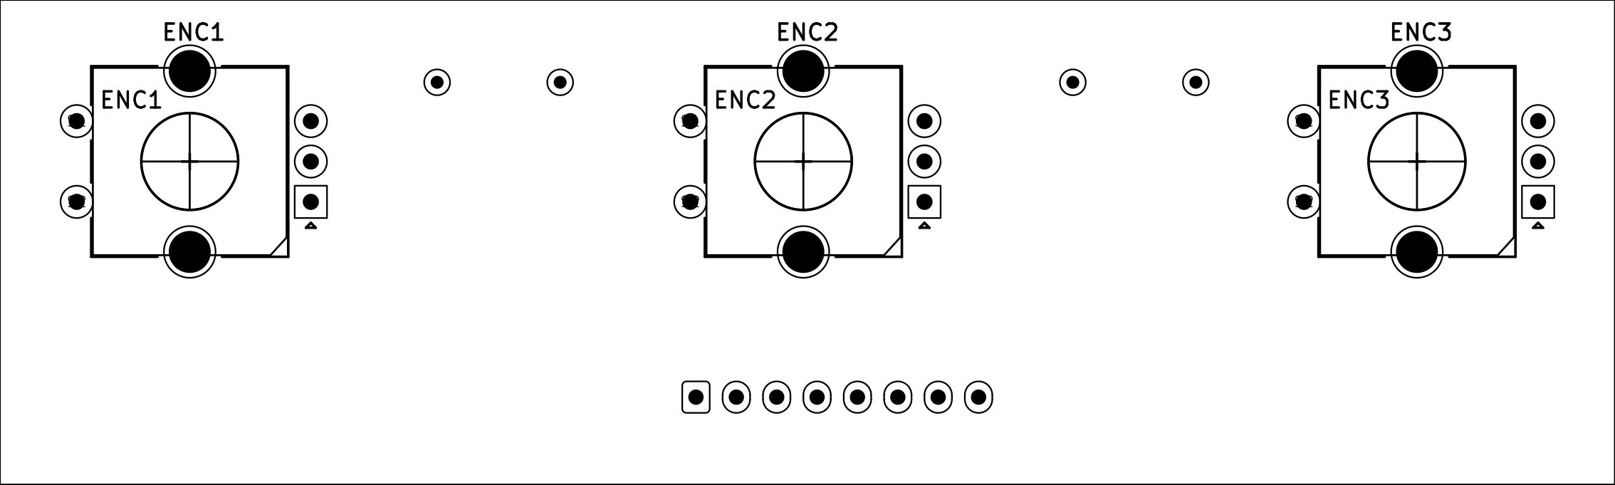
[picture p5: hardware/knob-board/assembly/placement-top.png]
knob board placement, top


- The three EC11 encoders go on the **top** side, J1, R1 and R2 on the **bottom**. The
  encoders' shield lugs solder to the ground pour.
- The switch ladder is on this board: ENC1 (MODE) switch direct to ground, ENC2 (BRIGHT)
  through R1 3.3 kΩ, ENC3 (GAIN) through R2 10 kΩ. The 10 kΩ pull-up and 100 nF
  debounce for that node live on the carrier, which is why the cable has no 3.3 V line.
- The bare board carries no MODE / BRIGHT / GAIN legend; that goes on the front panel.

**This board is the front-panel drilling template.** Knob shafts are on **38 mm centres**,
symmetric, 12 mm from each end of the 100 mm board, and 5 mm above the board's vertical
centreline. Clamp the bare board to the panel and spot the three holes through it, then
drill for the EC11's threaded bushing (7 mm thread; drill 7.2 mm).

## 4. Solder the mic board

| Ref | Part | Qty |
|---|---|---|
| J1 | JST B6B-XH-A | 1 |
| — | 1×3 pin header, 2.54 mm (mounts the INMP441 module) | 2 |
| — | INMP441 round breakout, Ø14 mm, two 1×3 rows 7.62 mm apart | 1 |

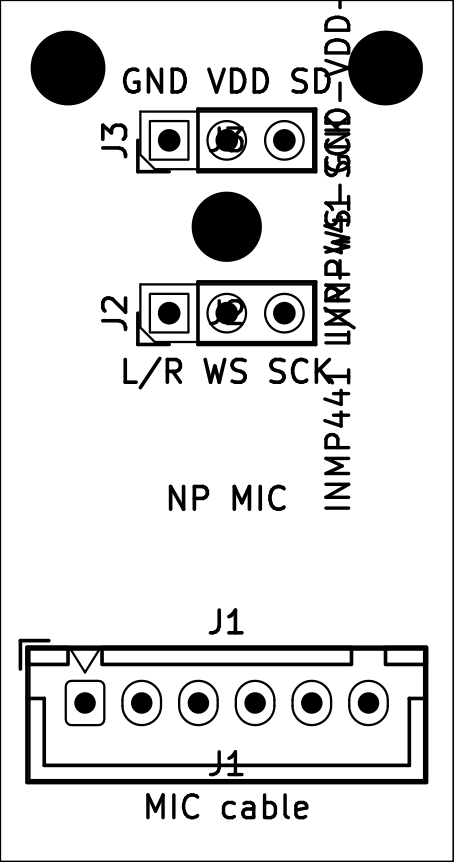
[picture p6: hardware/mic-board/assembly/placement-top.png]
mic board placement, top


Solder the two 1×3 headers and the JST. Mount the INMP441 module on the headers with its
**label / sound-port side up**, chip side toward the board. The Ø3 mm centre hole is
acoustic relief so either orientation still hears, but port-up makes the silk labels
match the module's. L/R is tied to ground on this board (left channel), which is what
the firmware expects. Two M3 holes, 14 mm apart, at the top corners.

## 5. Power and connector map

Off-board parts for this step:

| Part | Qty |
|---|---|
| JST-XH housings + crimp contacts (or pre-crimped XH leads): 8, 6 and 5 positions | 1 each |
| 2.54 mm female Dupont housing, 1×5 (Pi end of the J_PI cable) | 1 |
| Panel-mount DC jack, DC-099 style, 5.5 × 2.1 mm | 1 |
| SPST bat-handle toggle, ≥10 A DC | 1 |
| 18 AWG hookup wire for the DC-in and toggle legs | ~1 m |
| 5 V brick, 5.5 × 2.1 mm plug, ≥6 A | 1 |
| 16-pin HUB75 ribbon + panel power pigtail | ship with the panel |

```
wall → 5 V brick → panel-mount DC jack → J_PWR (VIN_RAW)
                                          │
                        J_SW ─ master toggle ─┘ (VIN_SW)
                                          │
                                   Q1 AOD403 (reverse-polarity)
                                          │ P5V
              ┌───────────────┬───────────┼─────────────┐
           J_PANEL           JP1         JP2 + JP3    (P3V3 comes back
        panel own thick   ESP32 5V pin   Pi pins 2, 4   from the devkit's
        power pigtail                    via J_PI       regulator)
```

| Connector | Pin | Net | Goes to |
|---|---|---|---|
| J_PWR | 1, 2 | VIN_RAW, GND | DC jack + and − |
| J_SW | 1, 2 | VIN_RAW, VIN_SW | The master toggle's two lugs (the toggle breaks the + rail) |
| J_PANEL | 1, 2 | P5V, GND | Panel power pigtail (red, black) |
| JP1 | | P5V → ESP_5V | Shunt = carrier powers the devkit |
| JP2, JP3 | | P5V → PI_5V_A / B | Shunts = carrier powers the Pi (two shunts so each carries ≤1.5 A) |
| J_HUB | 1–16 | HUB75 | Panel ribbon, straight |
| J_KNOBS | 1–8 | MODE_A, MODE_B, BRIGHT_A, BRIGHT_B, GAIN_A, GAIN_B, SW_LADDER, GND | Knob board J1, 1:1 |
| J_MIC | 1–6 | MIC_SCK, MIC_WS, MIC_SD, GND, P3V3, GND | Mic board J1, 1:1 |
| J_PI | 1–5 | PI_5V_A, PI_5V_B, GND, UART_RX, UART_TX | Pi header **pins 2, 4, 6, 8, 10** in that order |

**Wire colours.** No JST standard exists; the only rule is red for supplies, black for
ground, never either for a signal. The scheme used here (XH pin 1 is at the notched end
of the housing, matching the arrow on the silk):

| Pin | Mic (6P) | Knobs (8P) | Pi (5P) |
|---|---|---|---|
| 1 | MIC_SCK yellow | MODE_A yellow | PI_5V_A red |
| 2 | MIC_WS green | MODE_B orange | PI_5V_B red |
| 3 | MIC_SD white | BRIGHT_A green | GND black |
| 4 | GND black | BRIGHT_B blue | UART_RX green (Pi pin 8, TXD) |
| 5 | P3V3 red | GAIN_A white | UART_TX white (Pi pin 10, RXD) |
| 6 | GND black | GAIN_B grey | |
| 7 | | SW_LADDER brown | |
| 8 | | GND black | |

The Pi cable is deliberately straight: J_PI pin 4 (ESP32 RX, GPIO 17) lands on Pi pin 8
(TXD) and pin 5 (ESP32 TX, GPIO 18) on Pi pin 10 (RXD). The crossover is on the carrier.
Both sides are 3.3 V, no level shifter. 115200 8N1.

**Pull JP1 whenever a USB cable is plugged into the ESP32 devkit** while the carrier is
powered. The devkit has no reverse-current protection on USB VBUS; a live 5 V pin plus a
USB cable back-feeds your computer's port. Flash it with JP1 out (the devkit runs from
USB), then put the shunt back. JP2/JP3 out isolates the Pi the same way; pulling one of
them is also where you put an ammeter to measure Pi + screen current.

ESP32-S3 GPIO map, for reference (it is fixed by the firmware, not by this board):

| Function | GPIO | | Function | GPIO |
|---|---|---|---|---|
| HUB75 R1 G1 B1 | 4 5 6 | | Mic SCK WS SD | 38 39 40 |
| HUB75 R2 G2 B2 | 7 15 16 | | MODE A / B | 47 / 48 |
| HUB75 A B C D | 8 9 10 11 | | BRIGHT A / B | 1 / 12 |
| HUB75 LAT OE CLK | 13 14 21 | | GAIN A / B | 41 / 42 |
| UART RX / TX | 17 / 18 | | Switch ladder (ADC1) | 2 |

There are **no spare GPIOs**. Adding anything means removing something.

## 6. Bench test before seating anything

1. Nothing in the sockets, no Pi, no panel, all three shunts out. **The master toggle is
   in series with the + rail, so J_SW must be closed**: wire the toggle to it, or put a
   short jumper wire across the two J_SW terminals for the bench. Otherwise J_PWR reads
   5 V and J_PANEL reads nothing. Plug in the brick, toggle on. Measure 5 V (DC volts,
   red probe in the VΩ socket) at J_PANEL and at the P5V pin of JP1, JP2, JP3. Reverse the brick's polarity if you can and confirm
   nothing gets warm: Q1 should block.
2. Toggle off. Plug the panel ribbon into J_HUB and the panel pigtail into J_PANEL.
3. Seat the ESP32-S3 (already flashed and provisioned, see
   [`board1-firmware.md`](board1-firmware.md)). Shunt on JP1. Toggle on: the panel should
   come up with the Mountain spectrum within a few seconds.
4. Plug in the mic and knob cables. Speak: the spectrum should react. Turn the knobs.
5. Toggle off. Connect the Pi cable to header pins 2, 4, 6, 8, 10, shunts on JP2/JP3,
   screen on HDMI + USB. Toggle on. The Pi boots into the display app
   ([`board2-display.md`](board2-display.md)).

## 7. Enclosure

- Displays inset into the top of the body, control cavity routed from the rear, the DC
  jack on the rim through a jack plate. The brick stays outside: **no mains inside the
  wood**.
- Diffuser stack, front to back: Black LED acrylic → P95 Lighting White 69 % → ~5 mm air
  gap on nylon standoffs → the panel. Run the panel brighter to compensate. A black
  egg-crate grid in the air gap, one cell per LED, turns the soft glow into crisp
  Pixoo-style squares if you prefer that look.
- Mount the mic board where it hears the room, away from the Pi, with the port facing
  out through a small hole. Keep it off the panel's power leg.
- Passive cooling only. Any fan will be in the audio.
- The master toggle is a hard power cut. Make the Pi safe for that (read-only root or
  USB boot) before you close the box.

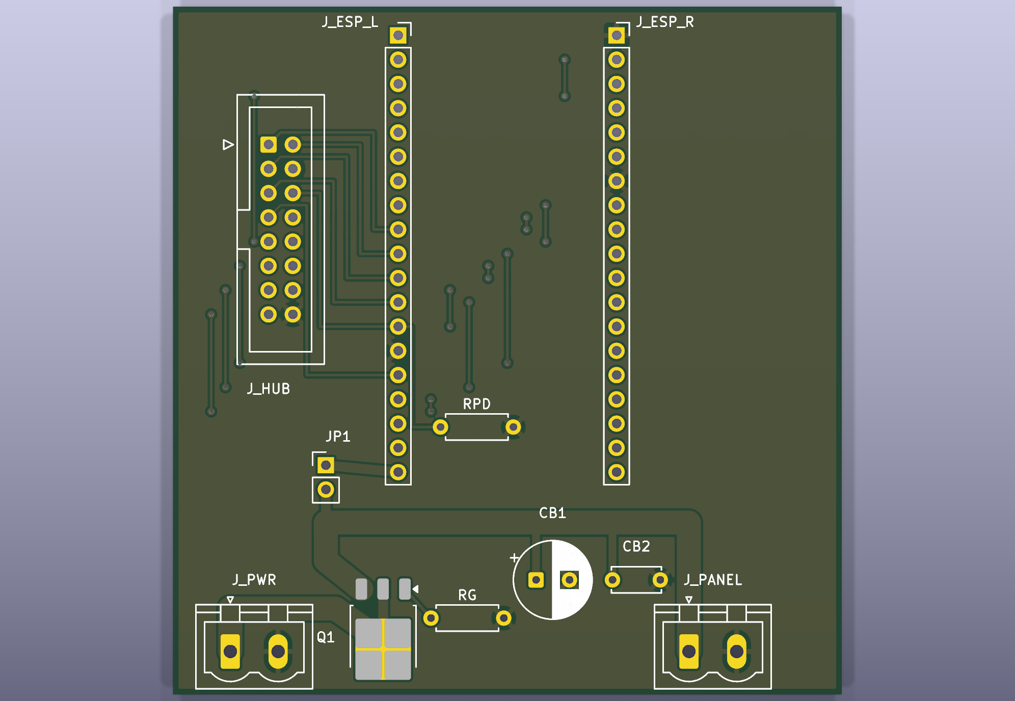
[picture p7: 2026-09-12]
hardware/panelboard/assembly/render-top.png

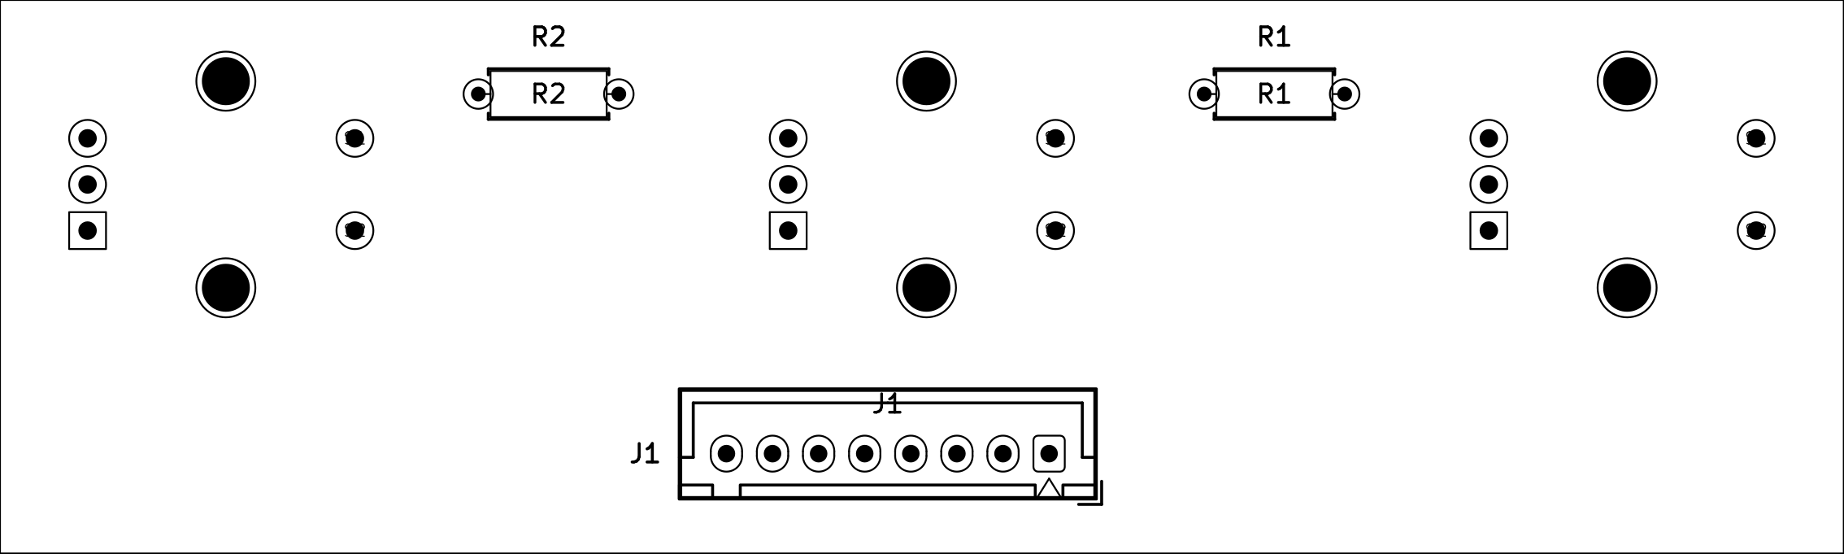
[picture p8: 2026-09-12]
hardware/knob-board/assembly/placement-bottom.png

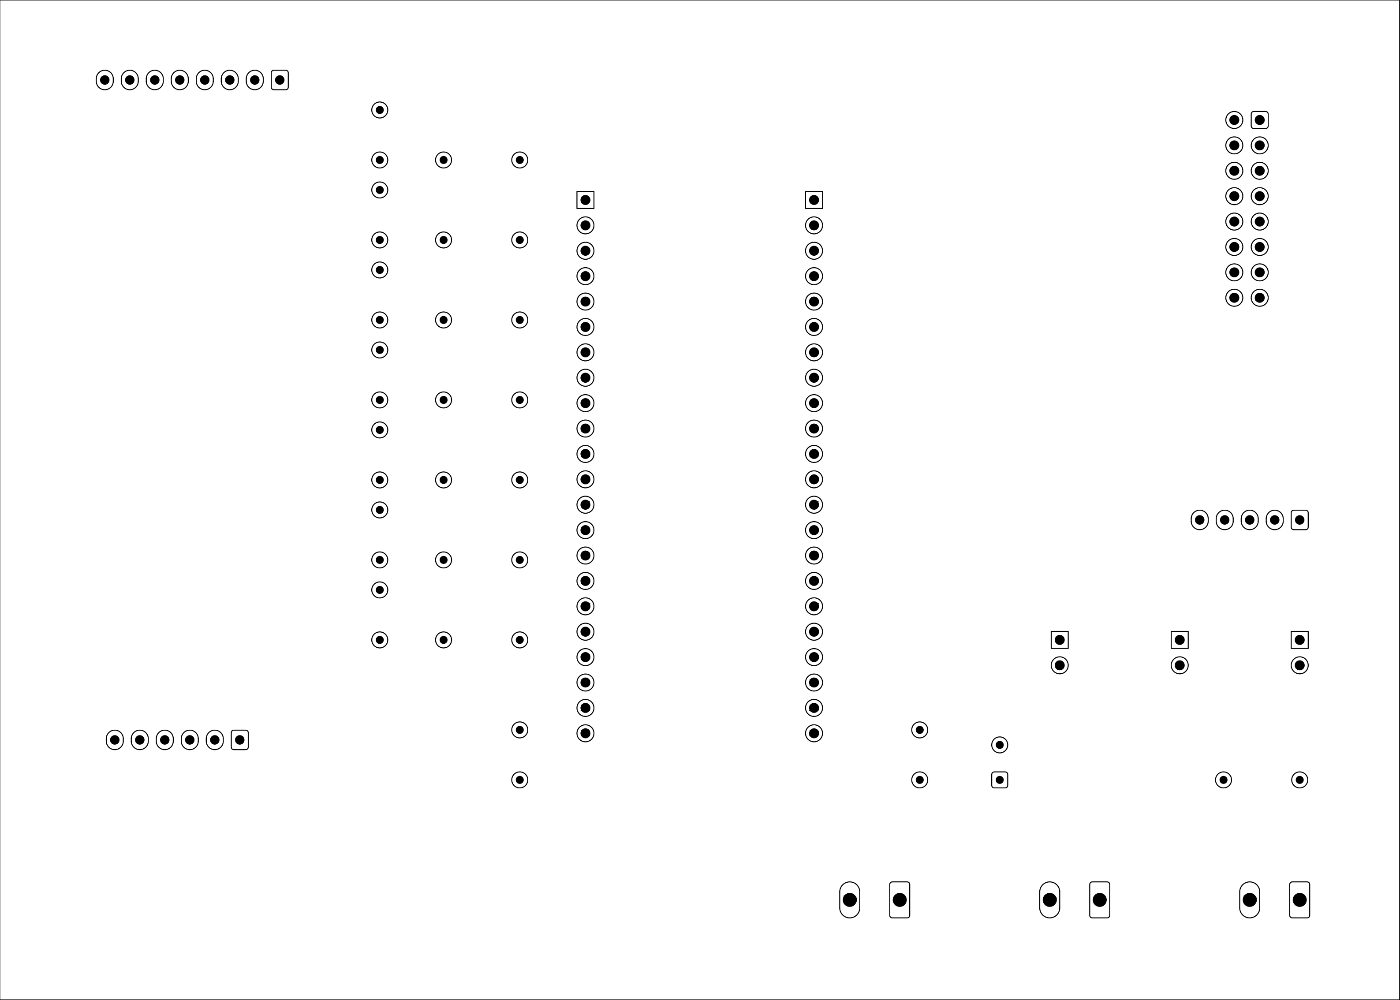
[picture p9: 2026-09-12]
hardware/carrier-board/assembly/placement-bottom.png

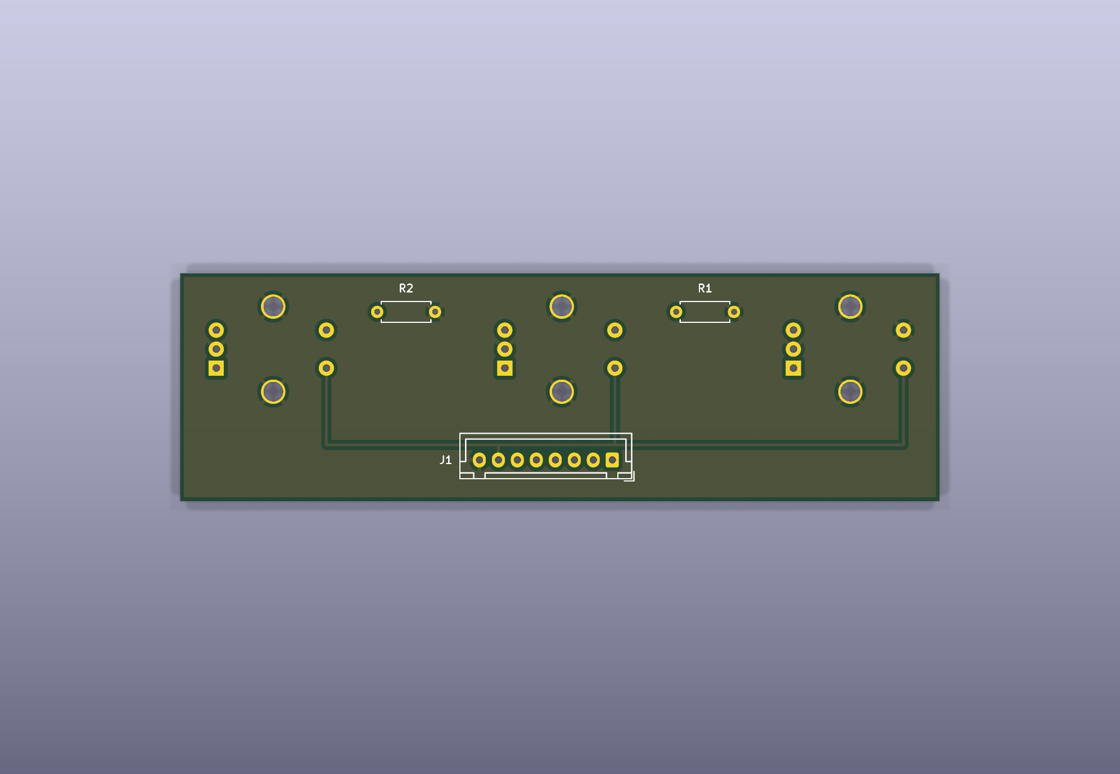
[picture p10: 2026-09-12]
hardware/knob-board/assembly/render-bottom.png

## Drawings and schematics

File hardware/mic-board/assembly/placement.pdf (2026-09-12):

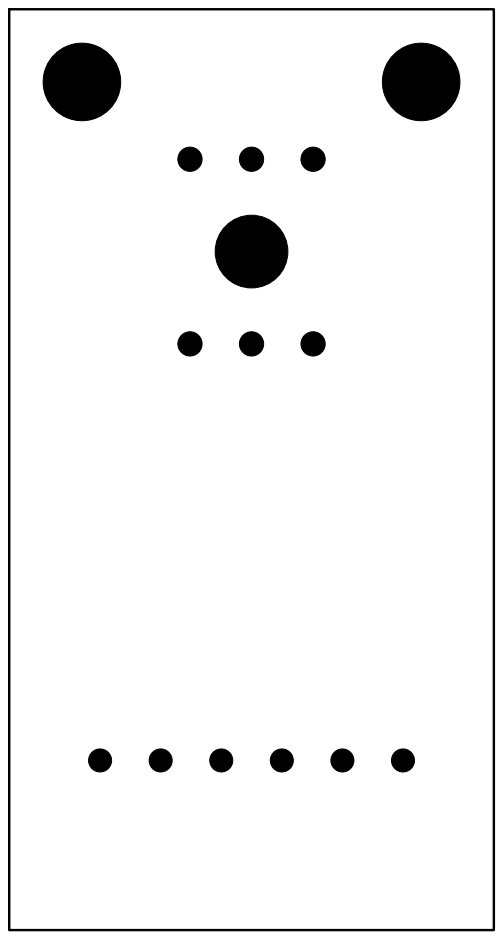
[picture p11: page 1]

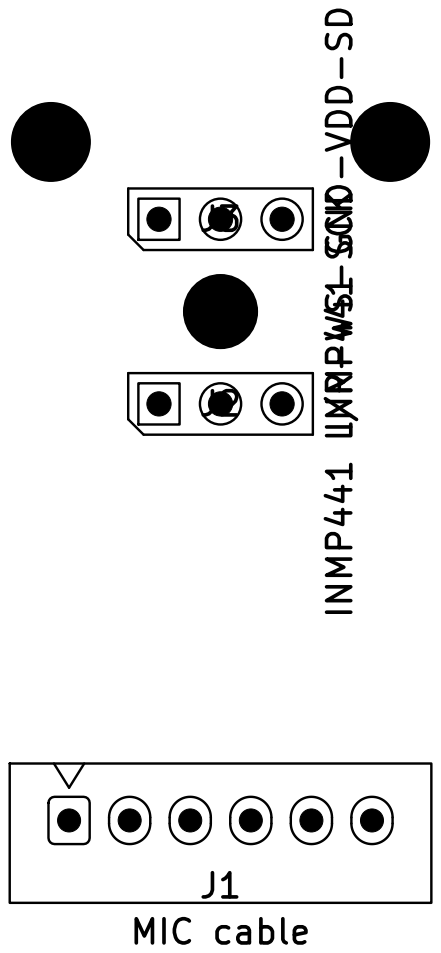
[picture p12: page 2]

INMP441 GND-VDD-SD J3 MIC cable

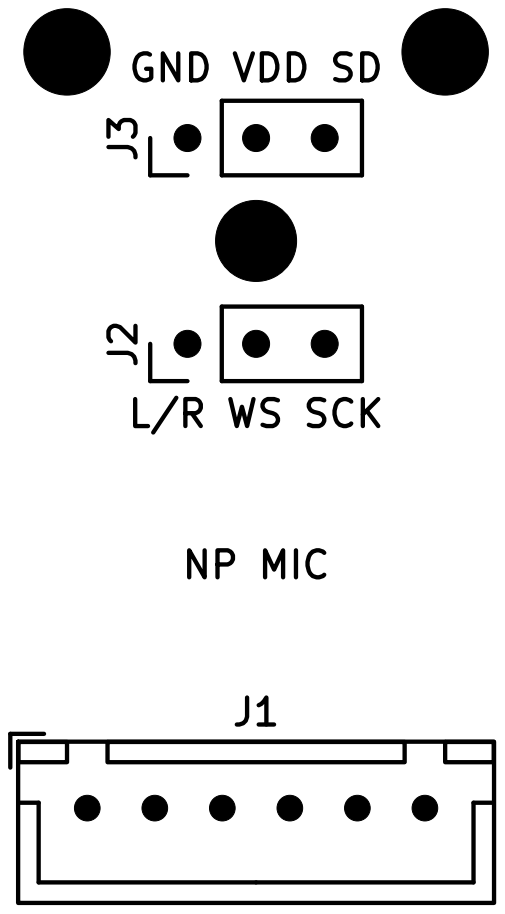
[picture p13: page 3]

GND VDD SD
L/R WS SCK NP MIC J3

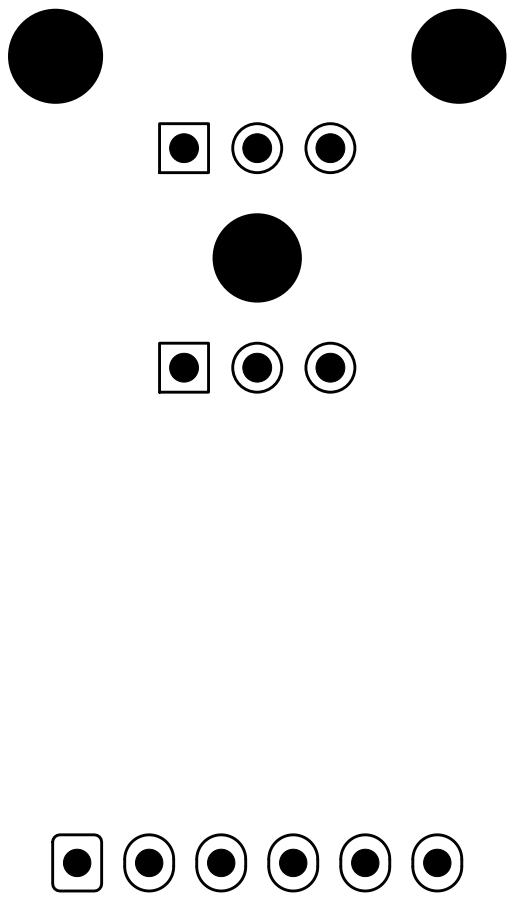
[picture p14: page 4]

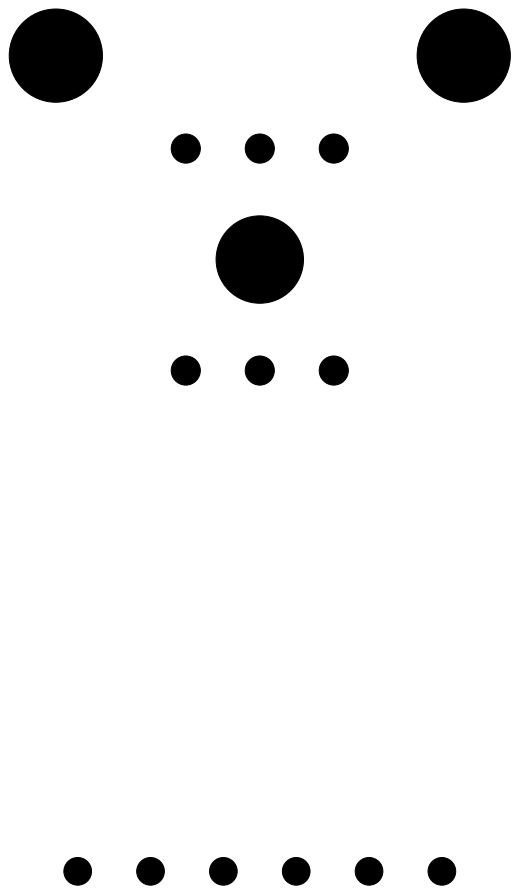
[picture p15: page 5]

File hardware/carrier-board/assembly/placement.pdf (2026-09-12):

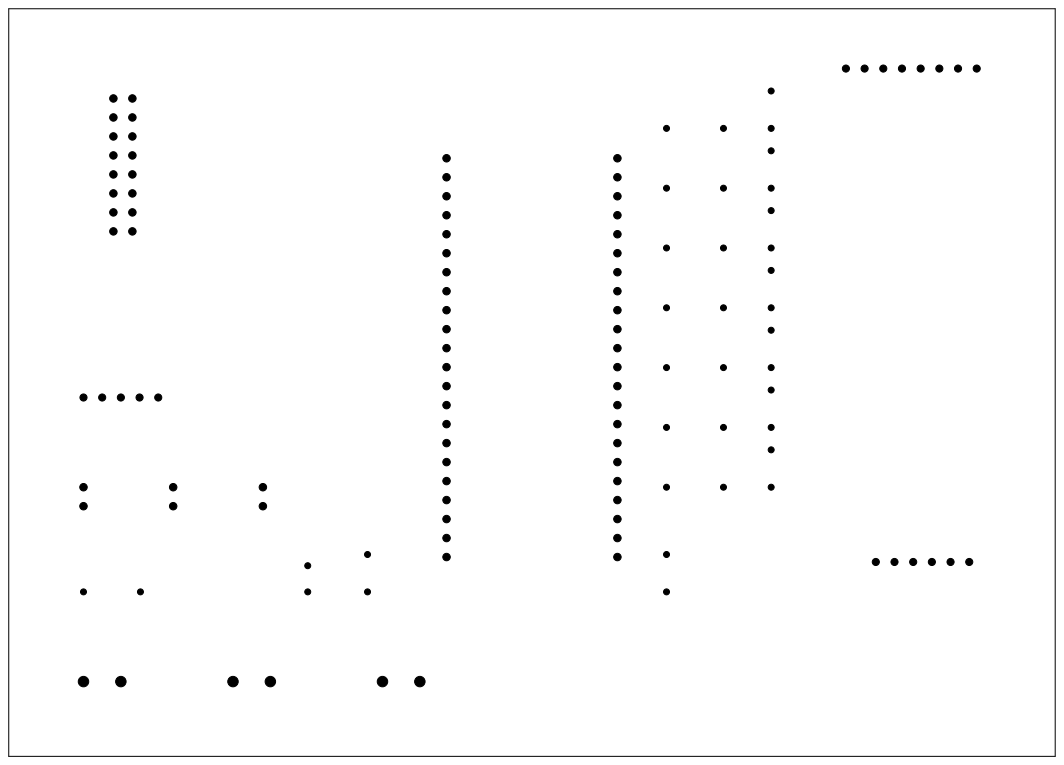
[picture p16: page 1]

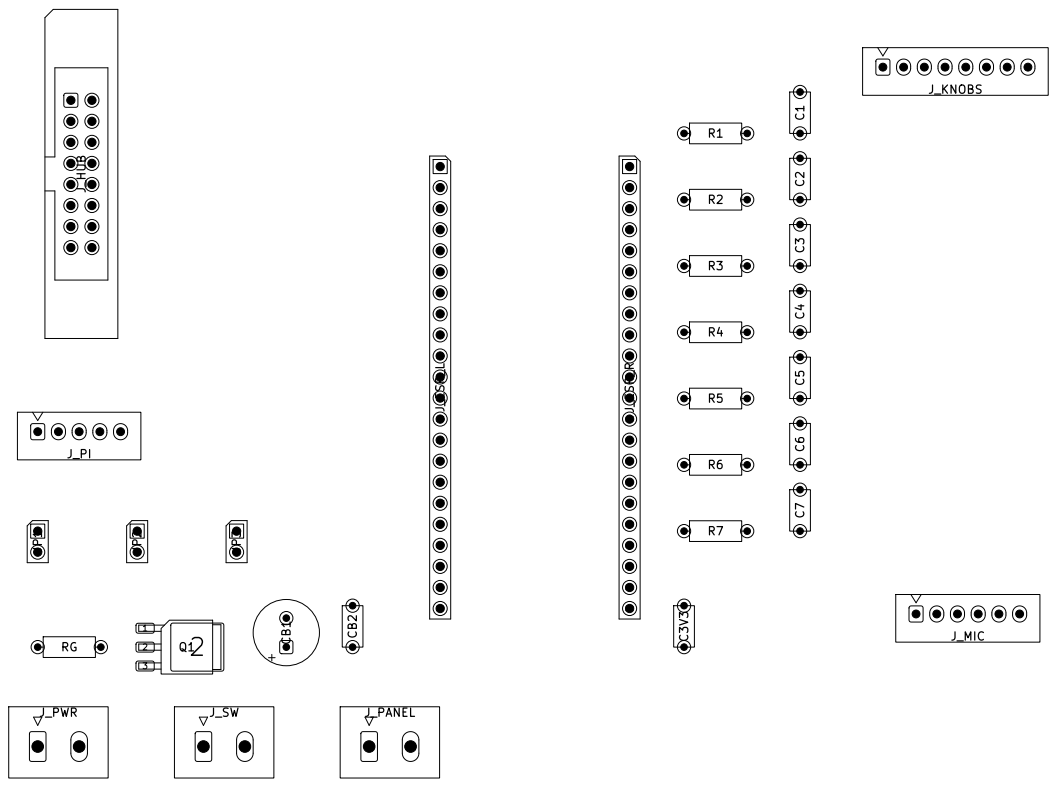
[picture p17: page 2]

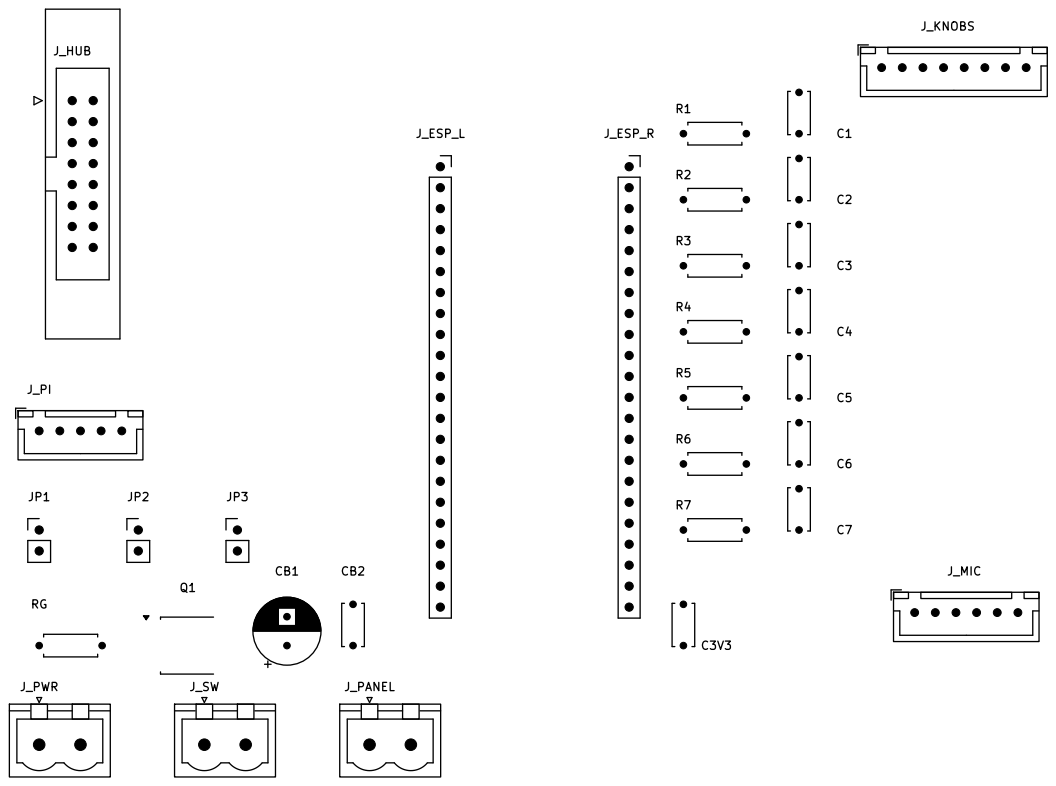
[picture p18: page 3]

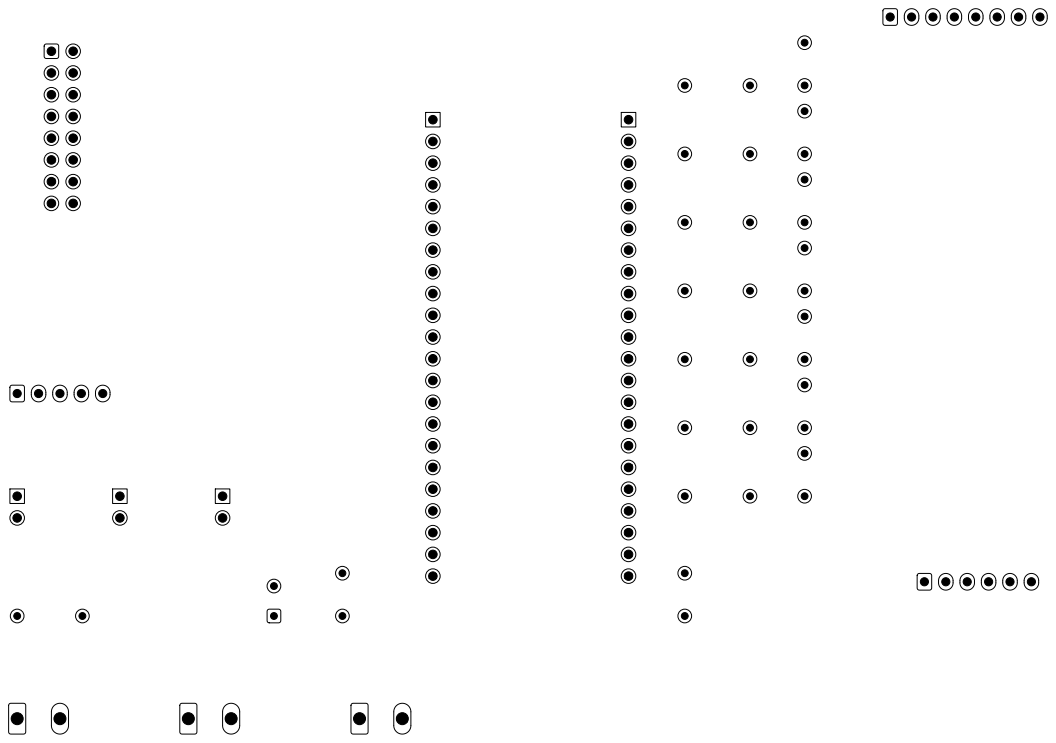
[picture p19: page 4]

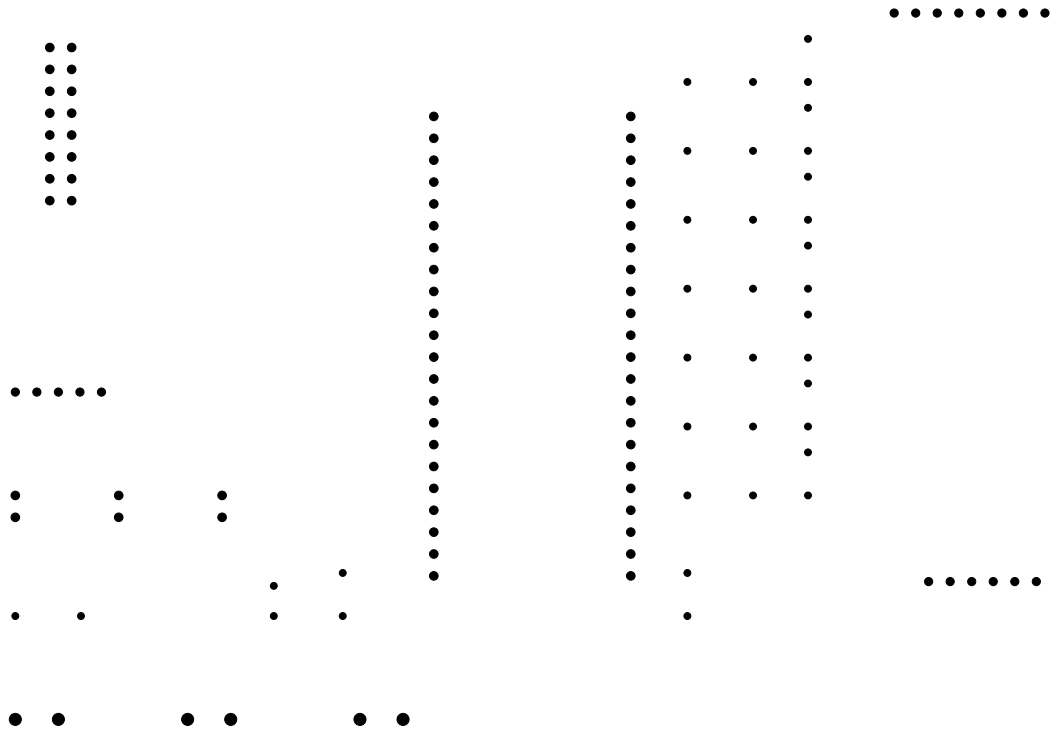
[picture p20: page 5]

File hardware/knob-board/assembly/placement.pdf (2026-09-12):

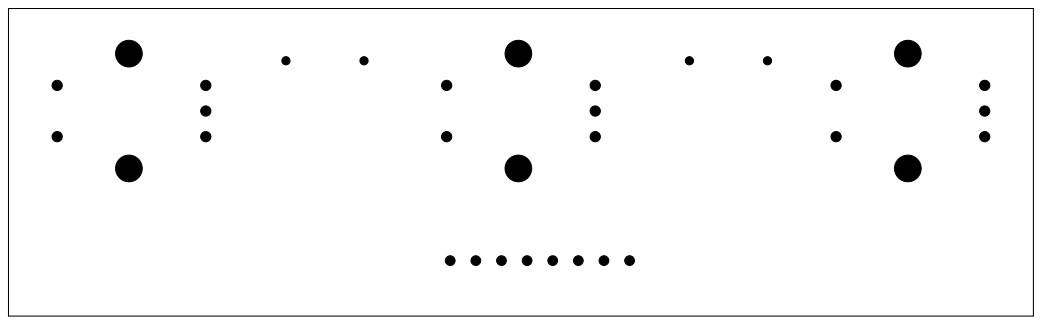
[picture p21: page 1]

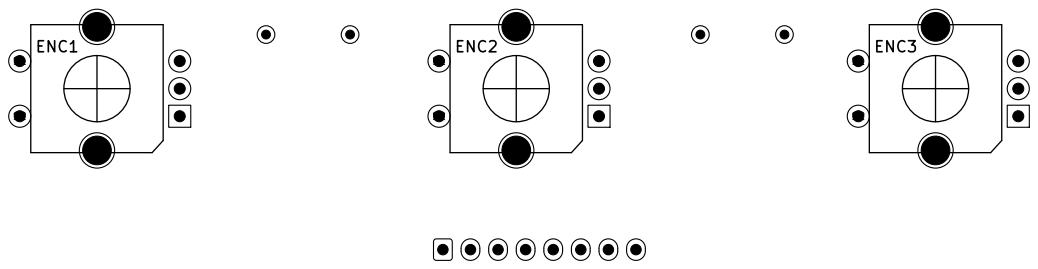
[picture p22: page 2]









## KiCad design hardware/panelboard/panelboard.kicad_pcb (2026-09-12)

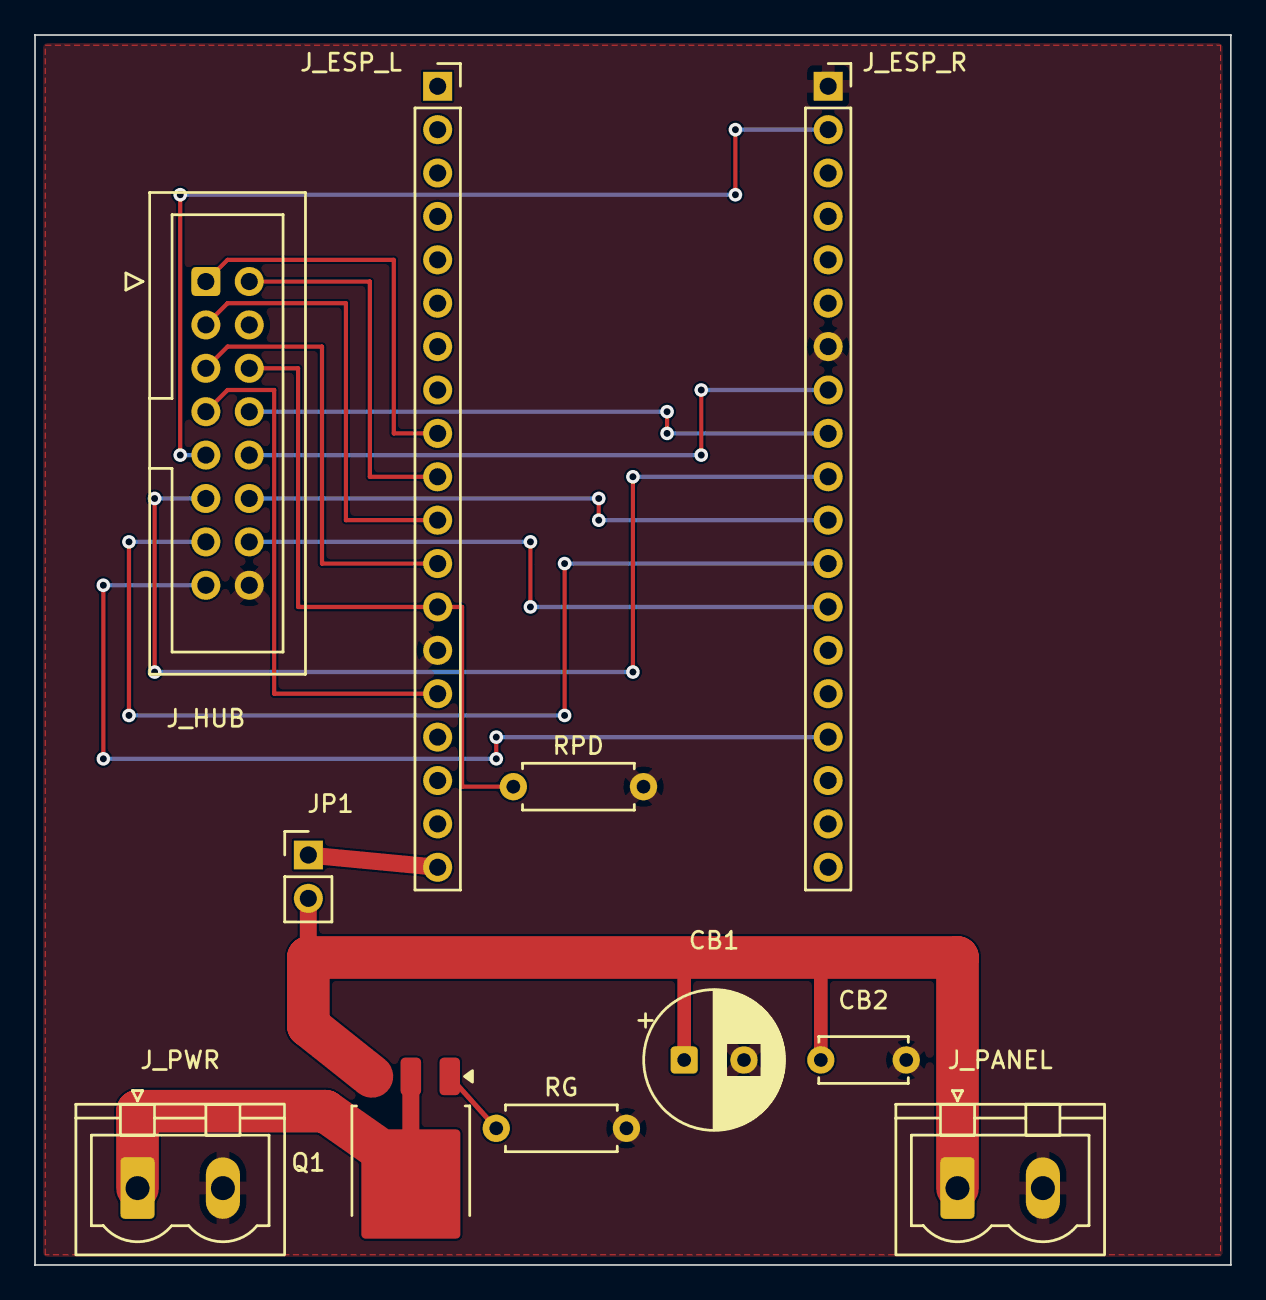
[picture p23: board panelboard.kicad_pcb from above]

Board: 2 copper layers, 70.0 x 72.0 mm, 11 parts (0 on the bottom side), 19 nets.

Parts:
CB1: 470uF/16V; CP_Radial_D8.0mm_P3.50mm
CB2: 100nF; C_Disc_D5.0mm_W2.5mm_P5.00mm
JP1: ESP 5V; PinHeader_1x02_P2.54mm_Vertical
J_ESP_L: ESP32 J1; PinSocket_1x19_P2.54mm_Vertical
J_ESP_R: ESP32 J3; PinSocket_1x19_P2.54mm_Vertical
J_HUB: HUB75; IDC-Header_2x08_P2.54mm_Vertical
J_PANEL: PANEL 5V; PhoenixContact_MSTBVA_2,5_2-G_1x02_P5.00mm_Vertical
J_PWR: DC IN 5V; PhoenixContact_MSTBVA_2,5_2-G_1x02_P5.00mm_Vertical
Q1: AOD403; TO-252-3_TabPin2
RG: 100k; R_Axial_DIN0207_L6.3mm_D2.5mm_P7.62mm_Horizontal
RPD: 10k; R_Axial_DIN0207_L6.3mm_D2.5mm_P7.62mm_Horizontal

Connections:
/ESP_5V: JP1.1, J_ESP_L.19
/GND: CB1.2, CB2.2, J_ESP_L.14, J_ESP_R.1, J_ESP_R.7, J_HUB.4, J_HUB.16, J_PANEL.2, J_PWR.2, RG.2, RPD.2
/HUB_A: J_ESP_R.2, J_HUB.9
/HUB_B: J_ESP_R.8, J_HUB.10
/HUB_B1: J_ESP_L.11, J_HUB.3
/HUB_B2: J_ESP_L.15, J_HUB.7
/HUB_C: J_ESP_R.10, J_HUB.11
/HUB_CLK: J_ESP_R.12, J_HUB.13
/HUB_D: J_ESP_R.11, J_HUB.12
/HUB_E: J_ESP_R.9, J_HUB.8
/HUB_G1: J_ESP_L.10, J_HUB.2
/HUB_G2: J_ESP_L.13, J_HUB.6, RPD.1
/HUB_LAT: J_ESP_R.13, J_HUB.14
/HUB_OE: J_ESP_R.16, J_HUB.15
/HUB_R1: J_ESP_L.9, J_HUB.1
/HUB_R2: J_ESP_L.12, J_HUB.5
/P5V: CB1.1, CB2.1, JP1.2, J_PANEL.1, Q1.3
/QG: Q1.1, RG.1
/VIN: J_PWR.1, Q1.2

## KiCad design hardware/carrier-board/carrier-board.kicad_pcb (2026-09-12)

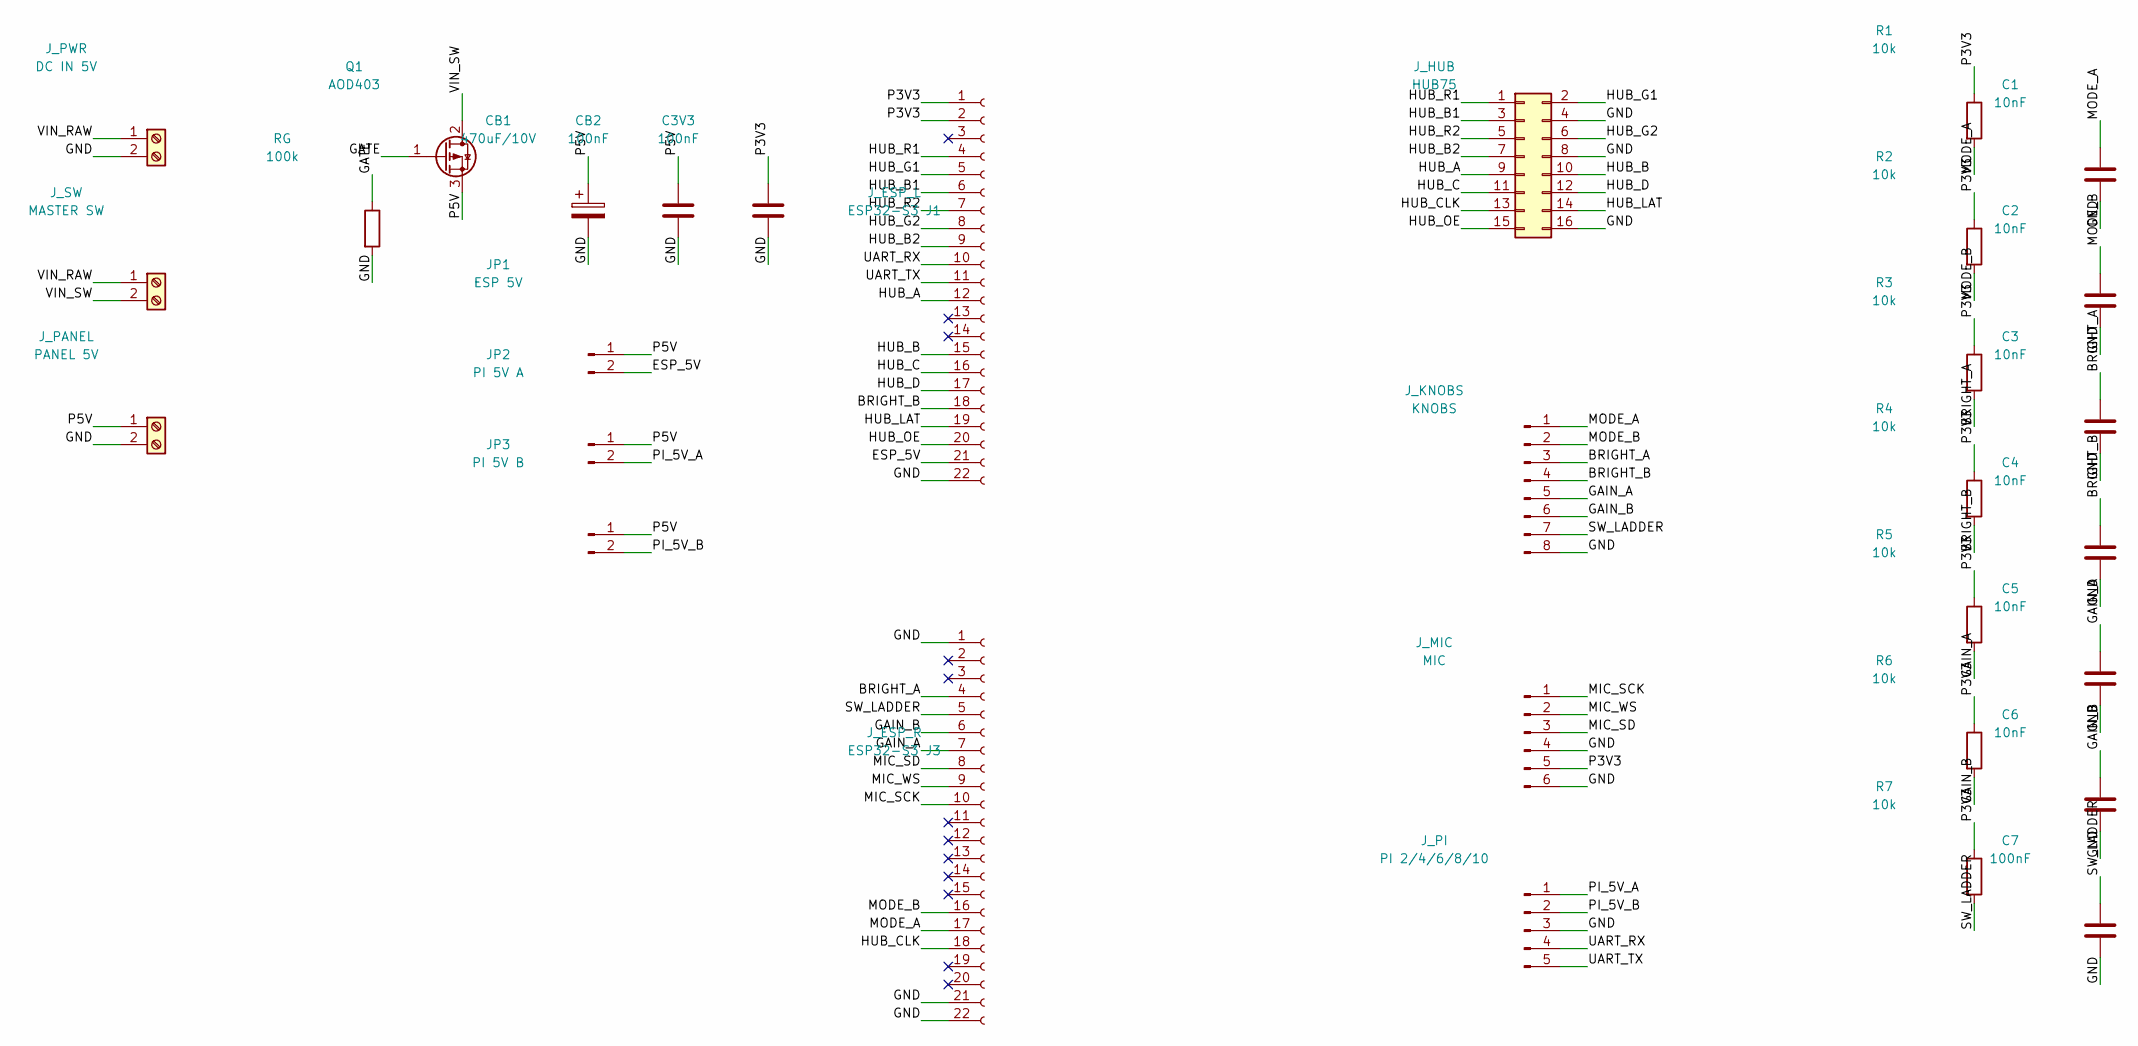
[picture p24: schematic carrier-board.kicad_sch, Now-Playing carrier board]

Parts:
C1, C2, C3, C4, C5, C6: 10nF; C_Disc_D5.0mm_W2.5mm_P5.00mm
C3V3, C7: 100nF; C_Disc_D5.0mm_W2.5mm_P5.00mm
CB1: 470uF/10V; CP_Radial_D8.0mm_P3.50mm
CB2: 100nF; C_Disc_D5.0mm_W2.5mm_P5.00mm
JP1: ESP 5V; PinHeader_1x02_P2.54mm_Vertical
JP2: PI 5V A; PinHeader_1x02_P2.54mm_Vertical
JP3: PI 5V B; PinHeader_1x02_P2.54mm_Vertical
J_ESP_L: ESP32-S3 J1; PinSocket_1x22_P2.54mm_Vertical
J_ESP_R: ESP32-S3 J3; PinSocket_1x22_P2.54mm_Vertical
J_HUB: HUB75; IDC-Header_2x08_P2.54mm_Latch_Vertical
J_KNOBS: KNOBS; JST_XH_B8B-XH-A_1x08_P2.50mm_Vertical; MPN B8B-XH-A(LF)(SN)
J_MIC: MIC; JST_XH_B6B-XH-A_1x06_P2.50mm_Vertical; MPN B6B-XH-A(LF)(SN)
J_PANEL: PANEL 5V; PhoenixContact_MSTBVA_2,5_2-G_1x02_P5.00mm_Vertical
J_PI: PI 2/4/6/8/10; JST_XH_B5B-XH-A_1x05_P2.50mm_Vertical; MPN B5B-XH-A(LF)(SN)
J_PWR: DC IN 5V; PhoenixContact_MSTBVA_2,5_2-G_1x02_P5.00mm_Vertical
J_SW: MASTER SW; PhoenixContact_MSTBVA_2,5_2-G_1x02_P5.00mm_Vertical
Q1: AOD403; TO-252-3_TabPin2; MPN AOD403
R1, R2, R3, R4, R5, R6, R7: 10k; R_Axial_DIN0207_L6.3mm_D2.5mm_P7.62mm_Horizontal
RG: 100k; R_Axial_DIN0207_L6.3mm_D2.5mm_P7.62mm_Horizontal

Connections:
/BRIGHT_A: C3.1, J_ESP_R.4, J_KNOBS.3, R3.2
/BRIGHT_B: C4.1, J_ESP_L.18, J_KNOBS.4, R4.2
/ESP_5V: JP1.2, J_ESP_L.21
/GAIN_A: C5.1, J_ESP_R.7, J_KNOBS.5, R5.2
/GAIN_B: C6.1, J_ESP_R.6, J_KNOBS.6, R6.2
/GATE: Q1.1 (G), RG.1
/GND: C1.2, C2.2, C3.2, C3V3.2, C4.2, C5.2, C6.2, C7.2, CB1.2, CB2.2, J_ESP_L.22, J_ESP_R.1, J_ESP_R.21, J_ESP_R.22, J_HUB.4, J_HUB.8, J_HUB.16, J_KNOBS.8, J_MIC.4, J_MIC.6, J_PANEL.2, J_PI.3, J_PWR.2, RG.2
/HUB_A: J_ESP_L.12, J_HUB.9
/HUB_B: J_ESP_L.15, J_HUB.10
/HUB_B1: J_ESP_L.6, J_HUB.3
/HUB_B2: J_ESP_L.9, J_HUB.7
/HUB_C: J_ESP_L.16, J_HUB.11
/HUB_CLK: J_ESP_R.18, J_HUB.13
/HUB_D: J_ESP_L.17, J_HUB.12
/HUB_G1: J_ESP_L.5, J_HUB.2
/HUB_G2: J_ESP_L.8, J_HUB.6
/HUB_LAT: J_ESP_L.19, J_HUB.14
/HUB_OE: J_ESP_L.20, J_HUB.15
/HUB_R1: J_ESP_L.4, J_HUB.1
/HUB_R2: J_ESP_L.7, J_HUB.5
/MIC_SCK: J_ESP_R.10, J_MIC.1
/MIC_SD: J_ESP_R.8, J_MIC.3
/MIC_WS: J_ESP_R.9, J_MIC.2
/MODE_A: C1.1, J_ESP_R.17, J_KNOBS.1, R1.2
/MODE_B: C2.1, J_ESP_R.16, J_KNOBS.2, R2.2
/P3V3: C3V3.1, J_ESP_L.1, J_ESP_L.2, J_MIC.5, R1.1, R2.1, R3.1, R4.1, R5.1, R6.1, R7.1
/P5V: CB1.1, CB2.1, JP1.1, JP2.1, JP3.1, J_PANEL.1, Q1.3 (S)
/PI_5V_A: JP2.2, J_PI.1
/PI_5V_B: JP3.2, J_PI.2
/SW_LADDER: C7.1, J_ESP_R.5, J_KNOBS.7, R7.2
/UART_RX: J_ESP_L.10, J_PI.4
/UART_TX: J_ESP_L.11, J_PI.5
/VIN_RAW: J_PWR.1, J_SW.1
/VIN_SW: J_SW.2, Q1.2 (D)

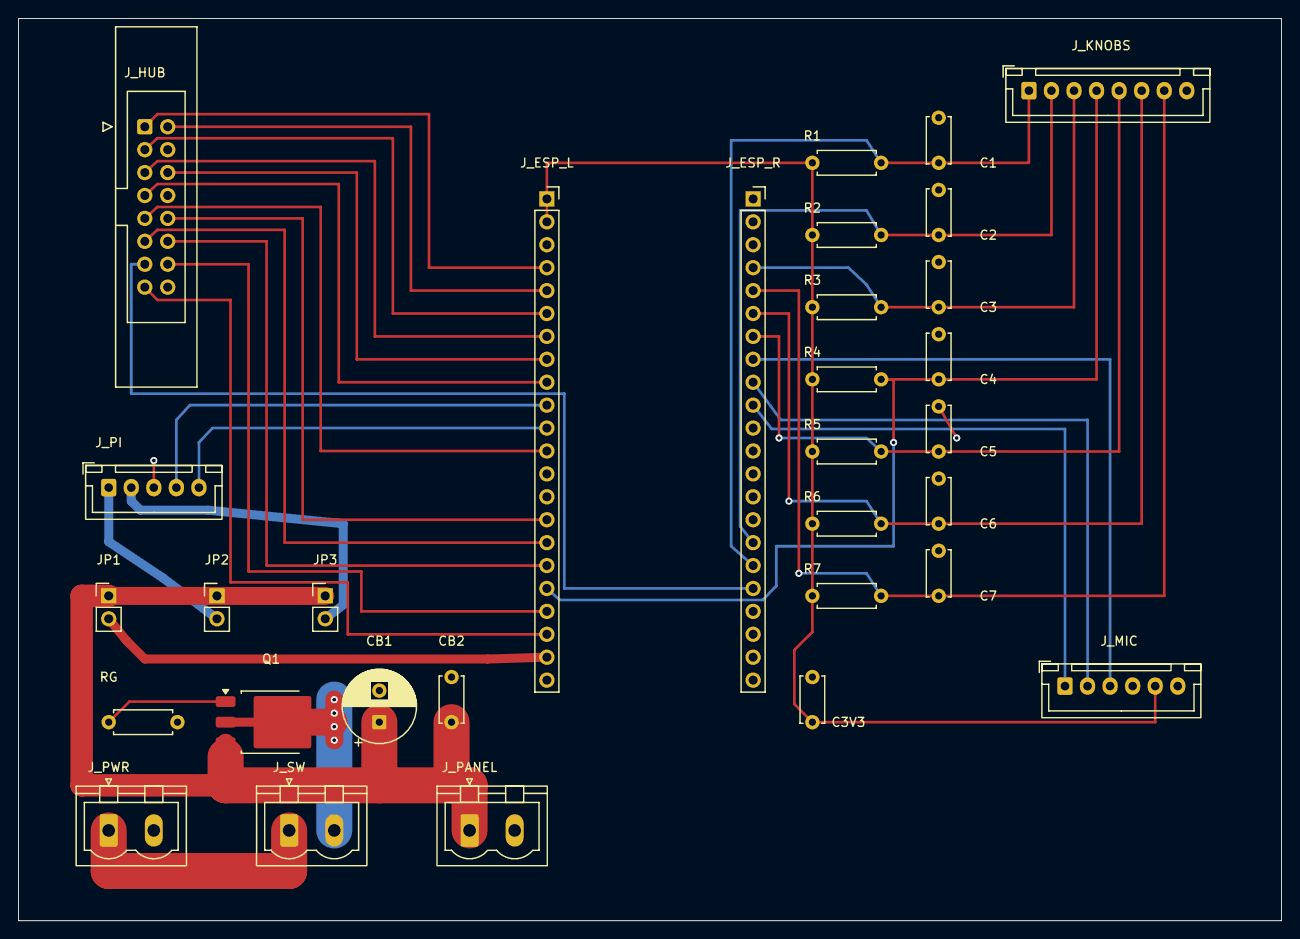
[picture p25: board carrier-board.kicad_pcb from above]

Board: 2 copper layers, 140.0 x 100.0 mm, 31 parts (0 on the bottom side), 34 nets.

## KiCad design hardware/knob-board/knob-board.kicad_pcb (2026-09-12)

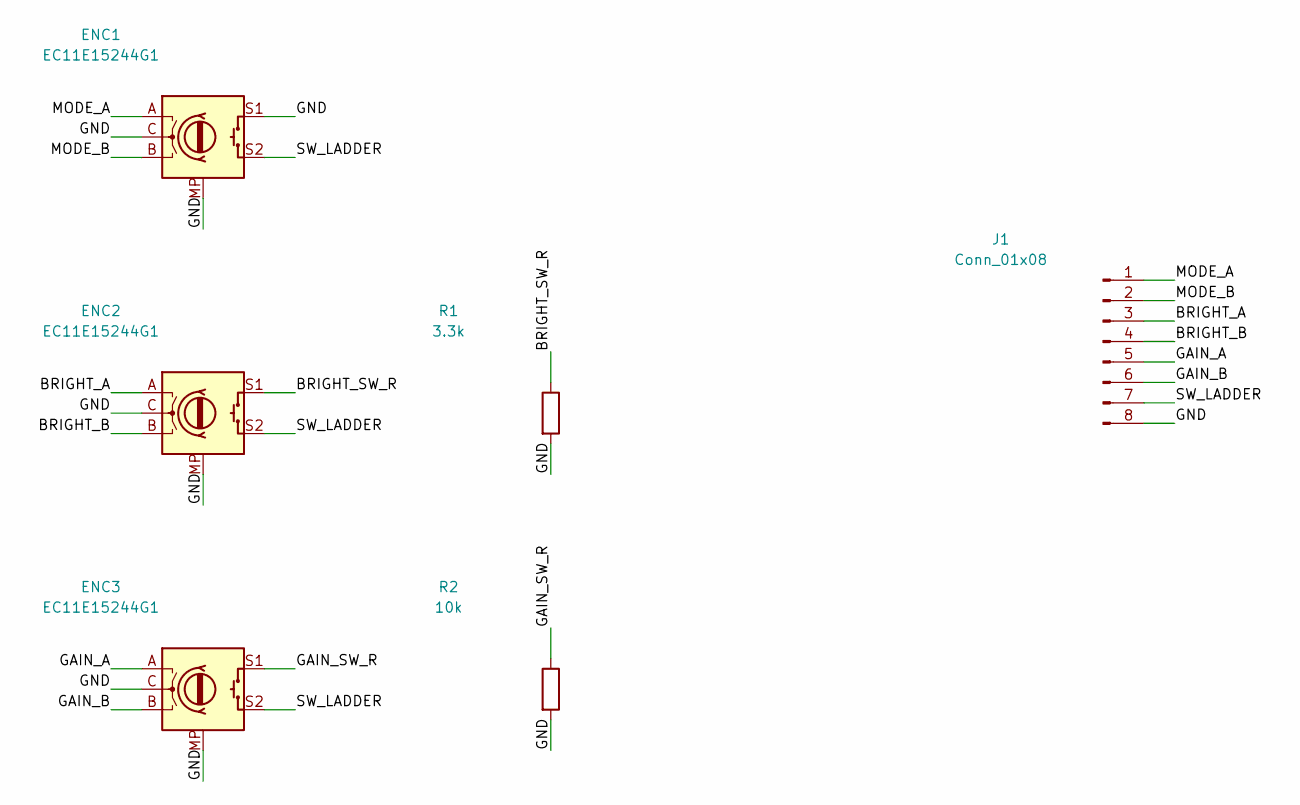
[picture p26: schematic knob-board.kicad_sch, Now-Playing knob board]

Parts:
ENC1, ENC2, ENC3: EC11E15244G1; RotaryEncoder_Alps_EC11E-Switch_Vertical_H20mm_CircularMoun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; MPN EC11E15244G1
J1: Conn_01x08; JST_XH_B8B-XH-A_1x08_P2.50mm_Vertical; MPN B8B-XH-A(LF)(SN)
R1: 3.3k; R_Axial_DIN0207_L6.3mm_D2.5mm_P7.62mm_Horizontal
R2: 10k; R_Axial_DIN0207_L6.3mm_D2.5mm_P7.62mm_Horizontal

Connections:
/BRIGHT_A: ENC2.A, J1.3
/BRIGHT_B: ENC2.B, J1.4
/BRIGHT_SW_R: ENC2.S1, R1.1
/GAIN_A: ENC3.A, J1.5
/GAIN_B: ENC3.B, J1.6
/GAIN_SW_R: ENC3.S1, R2.1
/GND: ENC1.C, ENC1.MP, ENC1.S1, ENC2.C, ENC2.MP, ENC3.C, ENC3.MP, J1.8, R1.2, R2.2
/MODE_A: ENC1.A, J1.1
/MODE_B: ENC1.B, J1.2
/SW_LADDER: ENC1.S2, ENC2.S2, ENC3.S2, J1.7

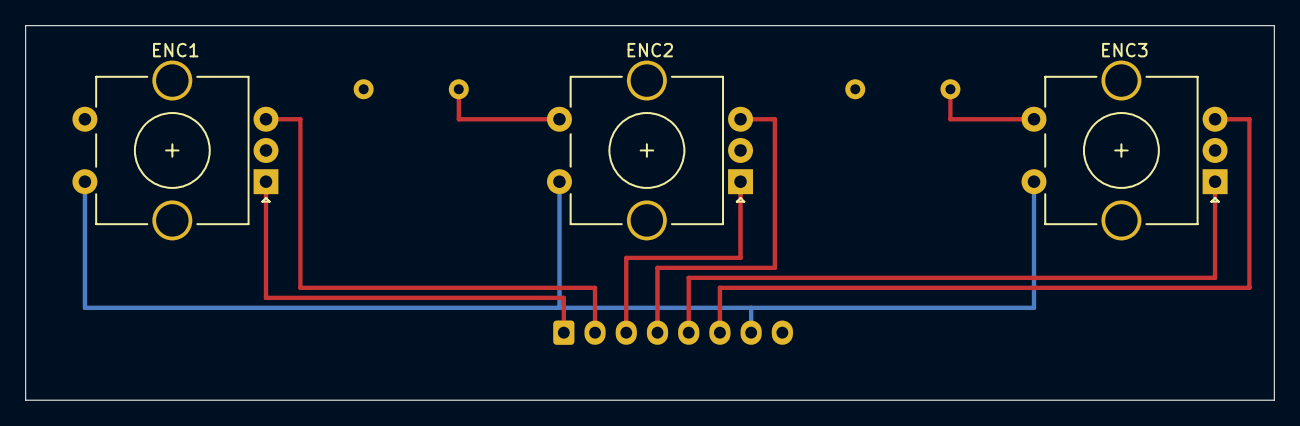
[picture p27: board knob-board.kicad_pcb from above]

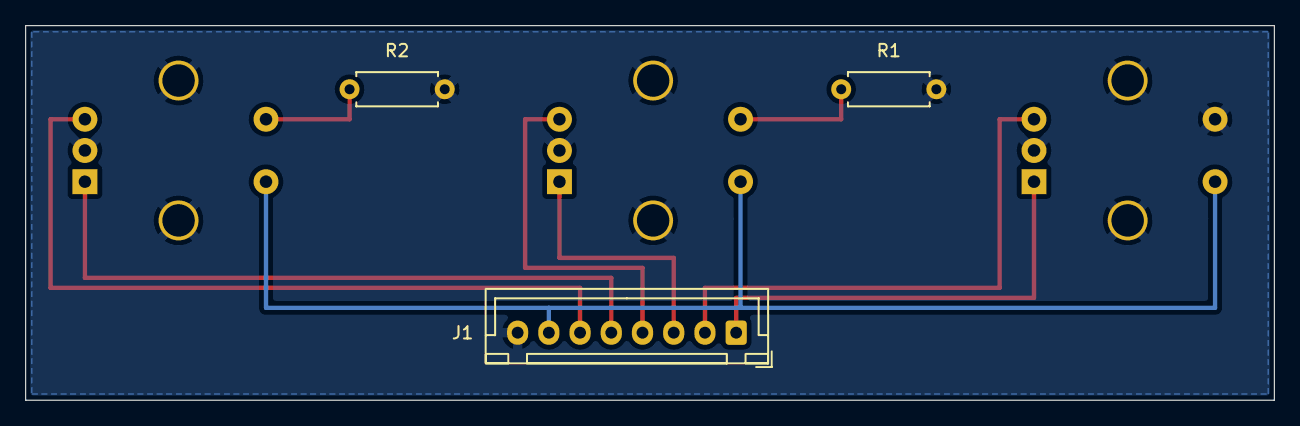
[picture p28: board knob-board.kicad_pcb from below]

Board: 2 copper layers, 100.0 x 30.0 mm, 6 parts (3 on the bottom side), 10 nets.

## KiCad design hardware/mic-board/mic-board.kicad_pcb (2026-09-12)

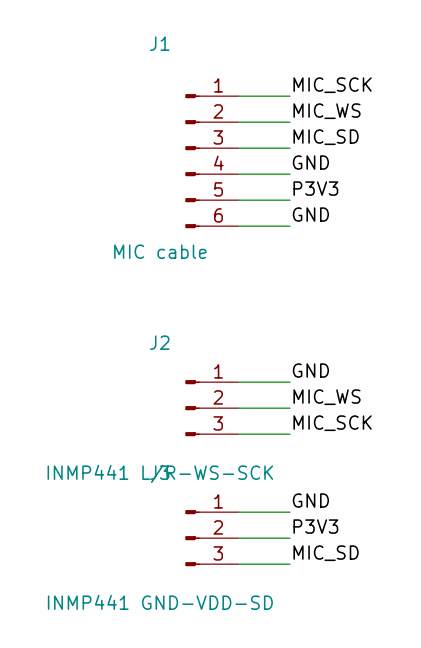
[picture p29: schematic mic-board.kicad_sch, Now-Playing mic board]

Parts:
J1: MIC cable; JST_XH_B6B-XH-A_1x06_P2.50mm_Vertical; MPN B6B-XH-A(LF)(SN)
J2: INMP441 L/R-WS-SCK; PinHeader_1x03_P2.54mm_Vertical
J3: INMP441 GND-VDD-SD; PinHeader_1x03_P2.54mm_Vertical

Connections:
/GND: J1.4, J1.6, J2.1, J3.1
/MIC_SCK: J1.1, J2.3
/MIC_SD: J1.3, J3.3
/MIC_WS: J1.2, J2.2
/P3V3: J1.5, J3.2

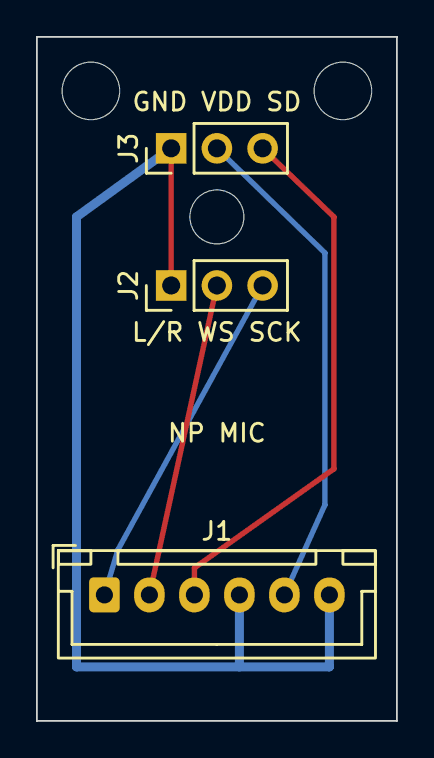
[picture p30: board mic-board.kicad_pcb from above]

Board: 2 copper layers, 20.0 x 38.0 mm, 6 parts (0 on the bottom side), 5 nets.

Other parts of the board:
H1, H2, H3: (no value)

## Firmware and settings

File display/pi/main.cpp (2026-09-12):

// Board 2 Pi entry point: drives the SHARED UI (../src/ui.cpp) on the real panel via
// LVGL's Linux DRM (default) or fbdev display driver + evdev touch — the same role
// ../sim/main.cpp plays with SDL. Everything below the platform layer (ui.cpp, the
// libcurl/stb_image backend.cpp, swipe paging) is reused unchanged.
//
//   cmake -S pi -B pi/build && cmake --build pi/build -j && ./pi/build/np-display
//   fbdev fallback:  cmake -S pi -B pi/build -DNP_USE_FBDEV=ON
//
// Config (host + shared token) comes from env NP_BASE_URL / NP_TOKEN (set in the
// systemd unit) — see backend.cpp; src/secrets.h is only the compile-time fallback.
#include "lvgl.h"
#include "ui.h"
#include "ui_platform.h"
#include "../sim/backend.h"   // reused verbatim; sim/ is NOT on the -I path (its lv_conf.h
                              // would shadow pi/lv_conf.h and silently disable the DRM driver)
#include <cstdio>
#include <cstdarg>
#include <cstdlib>
#include <ctime>
#include <unistd.h>

#ifndef NP_DRM_CARD
#define NP_DRM_CARD "/dev/dri/card0"
#endif
#ifndef NP_FB_DEV
#define NP_FB_DEV "/dev/fb0"
#endif
#ifndef NP_TOUCH_DEV
#define NP_TOUCH_DEV "/dev/input/event0"   // QDtech MPI5001 USB touch panel
#endif

static uint32_t now_ms(void) {
  struct timespec ts; clock_gettime(CLOCK_MONOTONIC, &ts);
  return (uint32_t)(ts.tv_sec * 1000u + ts.tv_nsec / 1000000u);
}

// --- UI platform shims (Pi) — declared in ui_platform.h, used by ui.cpp ---
uint32_t ui_millis(void) { return now_ms(); }
void ui_logf(const char *fmt, ...) { va_list ap; va_start(ap, fmt); vprintf(fmt, ap); va_end(ap); }
void ui_free(void *p) { free(p); }
size_t ui_free_psram(void) { return 0; }                       // no PSRAM on the Pi
void ui_request_album(const char *id) { backend_request_album(id); }  // tap -> real GET /album/{id}
void ui_clock_hhmm(char *out, size_t n) {                             // system localtime, 12h "H:MM"
  time_t t = time(nullptr); struct tm lt; localtime_r(&t, &lt);
  int h = lt.tm_hour % 12; if (h == 0) h = 12;
  snprintf(out, n, "%d:%02d", h, lt.tm_min);
}

// Mouse/touch-drag -> page swipe. Identical to the sim's swipe_tick — it's pure LVGL
// indev polling (no SDL), so the evdev pointer drives it unchanged. Latch a horizontal
// drag >=45px during the press (before the release's CLICKED fires), consume on release.
static void swipe_tick(lv_indev_t *indev) {
  static bool down = false;
  static int x0 = 0, y0 = 0;
  lv_point_t p; lv_indev_get_point(indev, &p);
  if (lv_indev_get_state(indev) == LV_INDEV_STATE_PRESSED) {
    if (!down) { down = true; x0 = p.x; y0 = p.y; g_swipe_request = 0; }
    int dh = p.x - x0, dv = p.y - y0;
    if (!g_swipe_request && abs(dh) >= 45 && abs(dh) > abs(dv))
      g_swipe_request = (dh < 0) ? +1 : -1;   // drag left -> NEXT, right -> PREV
  } else if (down) {
    down = false;
    if (g_swipe_request) {
      int req = g_swipe_request; g_swipe_request = 0;
      if (g_album_open) close_album();
      else if (card_idle && !lv_obj_has_flag(card_idle, LV_OBJ_FLAG_HIDDEN))
        mosaic_set_page((int)g_mosaic_page + req);
    }
  }
}

int main(void) {
  lv_init();
  lv_tick_set_cb(now_ms);

#ifdef NP_USE_FBDEV
  lv_display_t *disp = lv_linux_fbdev_create();
  lv_linux_fbdev_set_file(disp, NP_FB_DEV);
#else
  lv_display_t *disp = lv_linux_drm_create();
  lv_linux_drm_set_file(disp, NP_DRM_CARD, -1);   // -1 = auto-pick the connected connector
#endif
  (void)disp;

  lv_indev_t *touch = lv_evdev_create(LV_INDEV_TYPE_POINTER, NP_TOUCH_DEV);
  if (!touch) ui_logf("WARN: no touch indev on %s — display only\n", NP_TOUCH_DEV);

  build_ui();
  backend_init();   // real cloud data -> the shared UI (NP_BASE_URL / NP_TOKEN from env)

  for (;;) {
    uint32_t t = lv_timer_handler();
    backend_tick();          // poll /nowplaying (throttled) + reconcile mosaic tiles
    if (touch) swipe_tick(touch);
    progress_render(false);
    recheck_ui_tick();
    knob_toast_tick();
    usleep((t > 5 ? 5 : t) * 1000);
  }
  return 0;
}

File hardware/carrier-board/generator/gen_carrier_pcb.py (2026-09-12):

#!/usr/bin/env python3
"""Build carrier-board.kicad_pcb: outline, placement, routing, bottom GND pour.

One-off scaffolding; the .kicad_pcb it emits is the artifact that lives in git.

Board 140 x 100 mm, rect (10,10)-(150,110).  The ESP32-S3-DevKitC-1 sits in the middle
on two 1x22 sockets 22.86mm apart (Espressif's dimension drawing: 25.40mm board, rows
inset 1.27mm each side).  Placement follows the pin map: 12 of 13 HUB75 signals are on
J1 so the panel connector goes LEFT; the knobs and mic are on J3 so they go RIGHT.
The Pi is left too -- its UART is on J1 and its 5V comes from the power block.

Run with:  python3 gen_carrier_pcb.py <dest.kicad_pcb> [--dump]
"""
import sys, pcbnew
from pcbnew import VECTOR2I, FromMM as MM

FPDIR = "/usr/share/kicad/footprints"

BOARD = (10.0, 10.0, 150.0, 110.0)
TRACK_W, CLEAR = 0.30, 0.25
# 1oz outer copper.  IPC-2221 external: 6A at a 10C rise needs 3.56mm on 1oz
# (it was 1.78mm on 2oz, which is why this used to be 3.0).  4mm gives 6.5A @10C
# / 8.9A @20C -- the same ~2x margin over the 6A HUB75 full-white budget that the
# 2oz spin had.  Widening this is the whole point of the 1oz respin: do not drop
# it back to 3.0 without also going back to 2oz copper.
PWR_W = 4.0
SILK_W = 0.16   # JLC's minimum printable stroke is 0.153mm (6 mil), NOT 0.15

# ESP32 module: J1 (left) / J3 (right), pin 1 at the antenna end, both rows aligned.
ESP_X, ESP_Y = 80.0, 30.0           # centre-x of the module, y of pin 1
ROW = 22.86                          # 0.9" -- genuine DevKitC-1.  YD clone is 25.4 and won't fit.

NETS = {}


def net(board, name):
    # local labels on the root sheet come out of eeschema as "/NAME"; match that exactly
    # or every pad trips a net_conflict parity warning.
    if not name.startswith(("/", "unconnected-")):
        name = "/" + name
    if name not in NETS:
        n = pcbnew.NETINFO_ITEM(board, name)
        board.Add(n)
        NETS[name] = n
    return NETS[name]


def track(board, netname, layer, *pts, width=None):
    """Polyline of tracks through pts (mm tuples)."""
    n = net(board, netname)
    for a, b in zip(pts, pts[1:]):
        t = pcbnew.PCB_TRACK(board)
        t.SetStart(VECTOR2I(MM(a[0]), MM(a[1])))
        t.SetEnd(VECTOR2I(MM(b[0]), MM(b[1])))
        t.SetWidth(MM(width or TRACK_W))
        t.SetLayer(layer)
        t.SetNet(n)
        board.Add(t)


def via(board, netname, x, y):
    v = pcbnew.PCB_VIA(board)
    v.SetPosition(VECTOR2I(MM(x), MM(y)))
    v.SetDrill(MM(0.4))
    v.SetWidth(MM(0.8))
    v.SetNet(net(board, netname))
    board.Add(v)


def route(board):
    T, B = pcbnew.F_Cu, pcbnew.B_Cu

    # -- power block (6 A path at PWR_W) --
    # VIN_RAW dips south of the connector row to clear J_PWR.2 (GND).  y=104.5,
    # not 104: at 4mm the dip reaches 2mm each side of centre and y=104 leaves
    # only 0.20mm to the J_PWR.2 pad (which starts at 101.80).
    track(board, "VIN_RAW", T, (20, 100), (20, 104.5), (40, 104.5), (40, 100),
          width=PWR_W)
    # P5V trunk: Q1.3 south, east along y=95, north into J_PANEL; CB branches.
    # y=95, not 93: that centres the trunk in the 7.3mm corridor between the Q1
    # tab (ends 90.90) and the connector pad row (starts 98.20).  At 4mm the
    # trunk can no longer share that corridor with the VIN_SW crossing, so the
    # crossing moved wholly to the bottom layer -- see below.
    # 2.0 mm exit stub so the end cap clears Q1 pin 2 (2.28 mm pitch).
    track(board, "P5V", T, (32.96, 90.28), (32.96, 91.8), width=2.0)
    track(board, "P5V", T, (32.96, 91.8), (32.96, 95), (60, 95), (60, 100),
          width=PWR_W)
    track(board, "P5V", T, (50, 95), (50, 88), width=PWR_W)
    track(board, "P5V", T, (58, 95), (58, 88), width=PWR_W)
    # JP pin-1 rail fed around the west side (clears RG at x=20).  Carries the
    # ESP leg + both Pi legs, ~3.5A: 2.5mm is 4.6A @10C on 1oz, and the header
    # run east of JP1 has already shed the ESP leg so 2.0mm (3.9A) covers it.
    track(board, "P5V", T, (32.96, 95), (17, 95), (17, 74), (20, 74), width=2.5)
    track(board, "P5V", T, (20, 74), (44, 74), width=2.0)
    # VIN_SW: J_SW.2 is THT, so the crossing drops to the bottom layer *at the
    # pad* and runs the whole way under the P5V trunk -- one via farm at the
    # tab end instead of the two the old top-bottom-top hop needed.  Bottom is
    # clear here because Q1 is SMD, so this strap gets the full PWR_W.
    # 4 vias x ~2.2A (0.4mm drill, 25um barrel, IPC-2221) = 8.8A into the tab.
    track(board, "VIN_SW", B, (45, 100), (45, 85.5), width=PWR_W)
    for y in (85.5, 87.0, 88.5, 90.0):
        via(board, "VIN_SW", 45, y)
    track(board, "VIN_SW", T, (45, 85.5), (45, 90), width=2.0)
    track(board, "VIN_SW", T, (45, 88), (40, 88), width=3.0)     # via farm → tab
    track(board, "VIN_SW", T, (32.96, 88), (37, 88), width=1.0)  # pin 2 → tab strap
    track(board, "GATE", T, (32.96, 85.72), (22.3, 85.72), (20, 88))
    track(board, "ESP_5V", T, (20, 76.54), (22, 79), (24, 81), (62, 81),
          (68.57, 80.80), width=1.0)
    # -- HUB75 staircase: nested Ls, one lane per net; left-column pads entered
    # at mid-row height (slip between right pads) + short diagonal --
    # (net, esp_y, lane_x, target_y, hub_pad)
    # OE/LAT pins sit south of the JP rail (y=74): jog north at x 46.5/48 first
    track(board, "HUB_OE", T, (68.57, 78.26), (46.5, 78.26), (46.5, 72.5),
          (33.5, 72.5), (33.5, 41.2), (25.4, 41.2), (24, 39.78))
    track(board, "HUB_LAT", T, (68.57, 75.72), (48, 75.72), (48, 71.3),
          (35.5, 71.3), (35.5, 37.24), (26.54, 37.24))
    HUB_STAIR = [
        ("HUB_D",   70.64, 37.5, 34.70, (26.54, 34.70)),
        ("HUB_C",   68.10, 39.5, 33.43, (24.00, 34.70)),
        ("HUB_B",   65.56, 41.5, 32.16, (26.54, 32.16)),
        ("HUB_A",   57.94, 43.5, 30.89, (24.00, 32.16)),
        ("HUB_B2",  50.32, 45.5, 28.35, (24.00, 29.62)),
        ("HUB_G2",  47.78, 47.5, 27.08, (26.54, 27.08)),
        ("HUB_R2",  45.24, 49.5, 25.81, (24.00, 27.08)),
        ("HUB_B1",  42.70, 51.5, 23.27, (24.00, 24.54)),
        ("HUB_G1",  40.16, 53.5, 22.00, (26.54, 22.00)),
        ("HUB_R1",  37.62, 55.5, 20.60, (24.00, 22.00)),
    ]
    for name, ey, lx, ty, (px, py) in HUB_STAIR:
        pts = [(68.57, ey), (lx, ey), (lx, ty)]
        if ty == py:
            pts.append((px, py))
        else:
            pts += [(25.4, ty), (px, py)]
        track(board, name, T, *pts)
    # UART to the Pi on bottom (THT both ends; the staircase owns the top here)
    track(board, "UART_RX", B, (68.57, 52.86), (29, 52.86), (27.5, 54.5),
          (27.5, 62))
    track(board, "UART_TX", B, (68.57, 55.40), (31.5, 55.40), (30, 57),
          (30, 62))
    # -- P3V3: over the antenna end, then the resistor bus down x=98;
    # jog west at y 78-88 around C3V3.2 (GND, sits on the bus line) --
    track(board, "P3V3", T, (68.57, 32.54), (68.57, 26), (98, 26))
    track(board, "P3V3", T, (98, 26), (98, 78), (96, 80), (96, 86), (98, 88))
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

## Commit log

2026-06-30 Scaffold nowplaying-display: native LVGL Board-2 app (new design)
    New repo for the native LVGL display app, replacing the Chromium kiosk so
    it fits a 512 MB Pi (LVGL ~30-60 MB vs Chromium ~450 MB). Copies the proven
    SDL sim + cloud backend + contract structs from nowplaying/firmware/board2.
    NOTE: src/ui.cpp is ALREADY the new (kiosk) design, fully ported to LVGL
    on 2026-06-29 (4 screens + blur backdrop + RE-CHECK/knob/ear overlays) and
    hardware-verified — NOT the old design the handoff claimed. Sim builds and
    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
2026-06-30 pi: deploy the LVGL display on the Pi via DRM/KMS + evdev
    Adds the Pi platform layer that the sim's SDL main.cpp is to the desktop:
    LVGL on lv_linux_drm (default) or lv_linux_fbdev + lv_evdev touch, reusing
    src/ui.cpp, src/now_playing.h, and sim/backend.cpp unchanged. Only the entry
    point (pi/main.cpp) and pi/lv_conf.h differ from the sim.
    - pi/CMakeLists.txt mirrors sim/ but links libdrm instead of SDL; strips the
    ARM SIMD .S blend files (assembler chokes on them) and puts libdrm's include
    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
2026-07-01 Board 2 UI: Chrome-parity pass on the now-playing card
    Tighten the native-LVGL now-playing screen to the Chromium kiosk (the design
    source of truth), verified side-by-side in the SDL sim:
    - Backdrop: replace the flat/blocky raster with a smooth vertical colour
    gradient sampled from the cover — 16 band-average colours, low-pass smoothed
    into a gentle curve (≈ the kiosk's blur of the vertical profile), Bayer-
    dithered to RGB565, with the dark veil folded in per-row (the veil was a
    separate LVGL bg_grad that banded undithered). No cover detail survives; no
    visible steps.
    - Cover: round the corners via a clipping wrapper container — LVGL's own
    radius/clip_corner does not clip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
    [main.cpp]
2026-07-01 display: cache decoded art by url+maxdim so view switches are instant
    Re-entering RECENTLY (or re-opening an album) re-fetched and re-decoded all
    art synchronously, blocking the loop for ~1 s. The free-on-leave that forced
    this only exists to reclaim ESP32 PSRAM — harmless on the Pi, which has RAM to
    spare. Keep decoded tiles/covers keyed by url+maxdim; callers get a fresh copy
    they own, the cache keeps its own. Shared by sim + Pi (same backend.cpp).
2026-09-12 hardware: carrier, knob and mic board KiCad sources + JLCPCB fab zips
    [bom-jlc.csv, carrier-board.kicad_pcb, carrier-board.kicad_sch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]
2026-09-12 docs: README, BOM, assembly, Board 1 firmware, Board 2 display
2026-09-12 panelboard: standalone HUB75 driver board (KiCad, fab zip, build recipe)
    [panelboard.kicad_pcb, panelboard.kicad_sch]
2026-09-12 hardware: placement drawings (PNG/PDF) + 3D renders for every board, with the script that makes them
2026-09-12 assembly: inline per-board parts tables and placement drawings so each step is self-contained
2026-09-12 BOM: genuine DevKitC-1 sourcing (Mouser), N8R8 accepted with the 8MB partition table
2026-09-12 BOM: cite Espressif's dimension drawing for the 22.86 mm row spacing
2026-09-13 assembly: bench test must close J_SW (toggle or jumper) before J_PANEL reads anything
2026-09-13 assembly: wire colour scheme for the mic, knob and Pi cables
